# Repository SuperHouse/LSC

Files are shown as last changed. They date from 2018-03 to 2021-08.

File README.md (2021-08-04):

Home Automation Light Switch Controller
=======================================

Copyright 2019-2021 SuperHouse Automation Pty Ltd  www.superhouse.tv

A modular Light Switch Controller for DIY home automation projects.

This system uses UTP cable (typically Cat-5e because it's cheap) to
connect light switches to a central controller. The light switches
can be either very simple buttons or switches mounted in wall plates,
or smart switches with a microcontroller embedded.

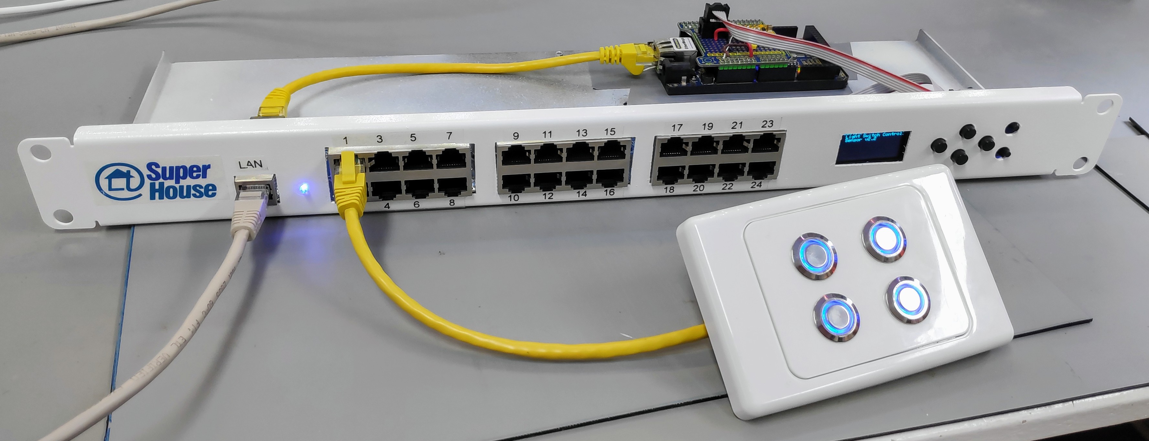
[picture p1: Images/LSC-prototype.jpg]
Light Switch Controller prototype


The LSC provides 12V power down the line to each wall plate, which can
be used for LED illumination or to power more advanced light switches.

Light switches pull one of 4 signal wires in the cable to 0V to indicate
that they have been activated. The LSC pulls the signal wires high
internally and detects when they are pulled low.

RJ45 sockets on the LSC are connected to I/O channels via I2C
addressable I/O buffers. Each RJ45 socket provides connections for
GND, 12V, and 4 signal lines.

An LSC can be built with different numbers of ports and interface
options.

The design files for the I2C to RJ45 breakouts are now in a separate
repository:

  https://github.com/SuperHouse/I2CRJ45

Features:

 * RJ45 sockets for connection to light switches over Cat-5
 * I2C interface with interrupt output

More information:

  http://www.superhouse.tv/lsc

INSTALLATION
------------
The design is saved as an EAGLE project. EAGLE PCB design software is
available from www.cadsoftusa.com free for non-commercial use. To use
this project download it and place the directory containing these files
into the "eagle" directory on your computer. Then open EAGLE and
navigate to the project.

FIRMWARE
--------
See [Universal State Monitor](https://github.com/SuperHouse/USM) for 
firmware which is compatible with the LSC.

CREDITS
-------
 * Jonathan Oxer jon@oxer.com.au

DISTRIBUTION
------------
The specific terms of distribution of this project are governed by the
license referenced below.

LICENSE
-------
Licensed under the TAPR Open Hardware License (www.tapr.org/OHL).
The "license" folder within this repository also contains a copy of
this license in plain text format.

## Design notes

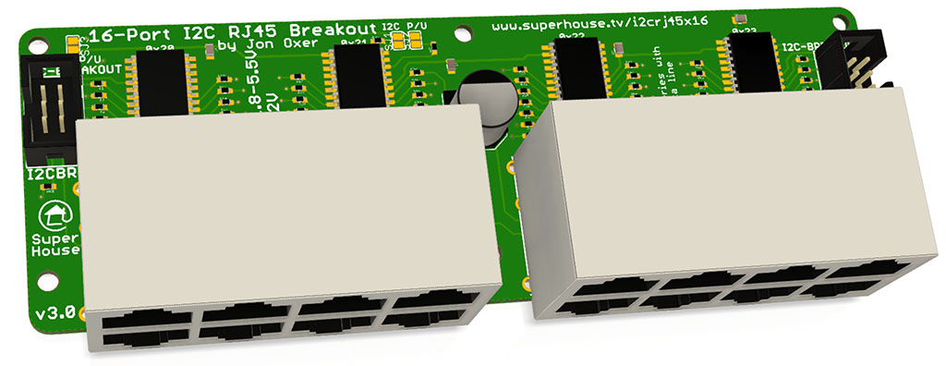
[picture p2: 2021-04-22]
Images/I2CRJ45X16-v3_0-render.jpg

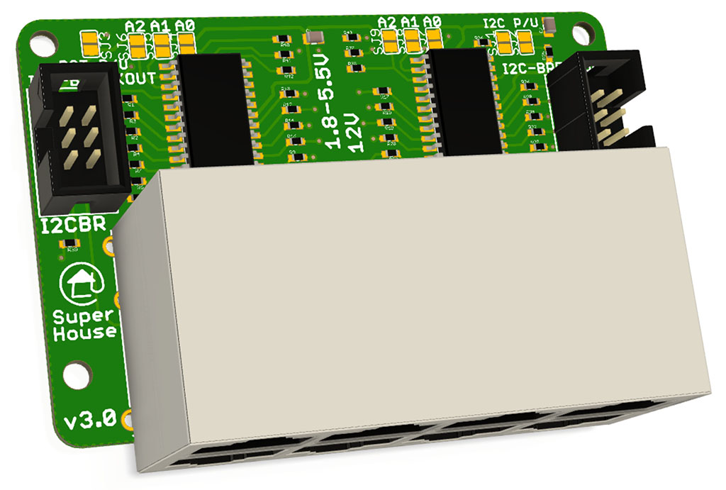
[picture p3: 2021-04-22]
Images/I2CRJ45X8-v3_0-render.jpg

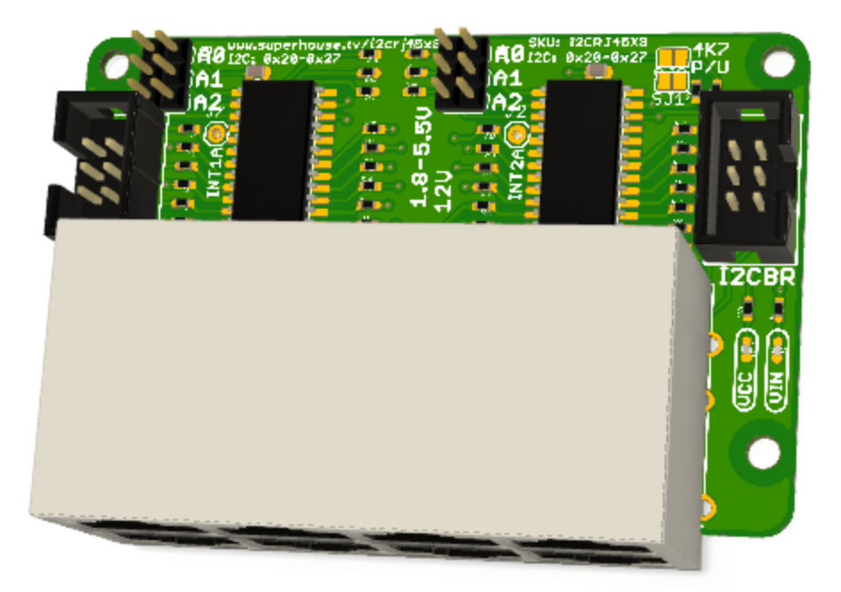
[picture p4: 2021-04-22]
Images/I2CRJ45X8-v2_2-render.jpg

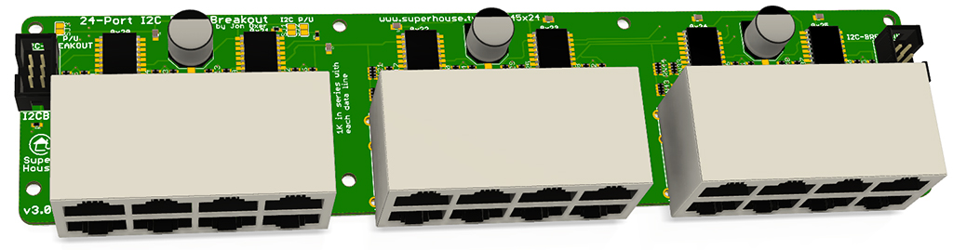
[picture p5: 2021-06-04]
Images/I2CRJ45X24-v3_0-render.jpg

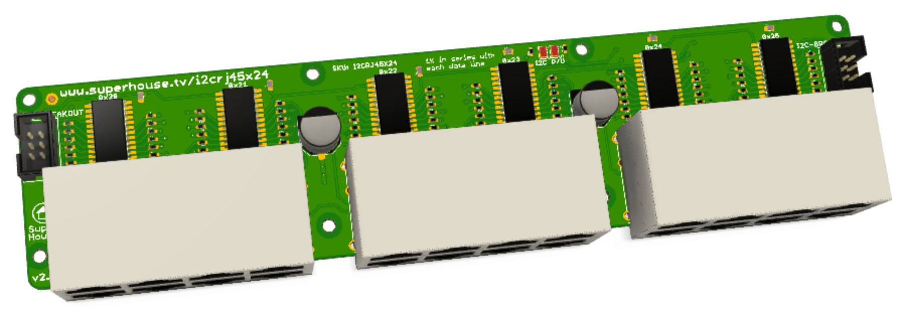
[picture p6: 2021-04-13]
Images/I2CRJ45X24-v2_2-render.jpg

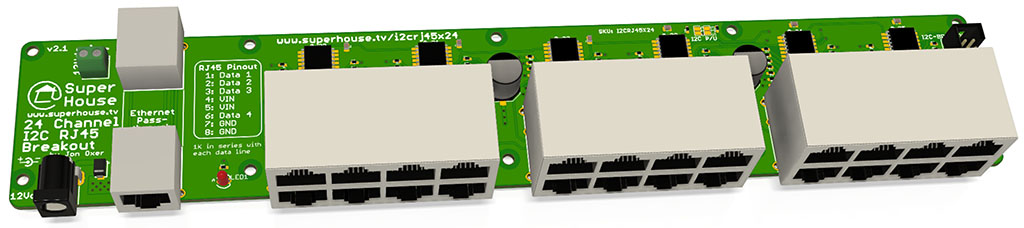
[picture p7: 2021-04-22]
Images/I2CRJ45X24PT-v2_1-render.jpg

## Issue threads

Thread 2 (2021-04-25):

Auto discover MCP23017

jonoxer, 2021-04-25:
Suggestion by Austin: scan I2C at startup and auto configure for number of input ports.

austinscreations, 2021-04-25:
could also be a way of detecting a failure, / outputting a warning to mqtt
glad you like the suggestion.

Sausages69, 2021-04-25:
Great idea :)

jonoxer, 2021-04-25:
This has been implemented by @sumnerboy12 using a scan starting at the base address, and ending at the first gap. This meets our short-term needs, but ultimately this needs to scan the entire range and skip any addresses that don't reply. The reason is that the control buttons on the OLED front panel are also on an MCP23017 but separate to the rest of the inputs, and it's always at the highest address. It will never be discovered if the scan stops at the first gap.

I'm leaving this issue open for now as a reminder for the future.

sumnerboy12, 2021-04-26:
See https://github.com/SuperHouse/LSC/pull/10 for further work on this.

sumnerboy12, 2021-04-26:
The code should now detect the OLED input button events and report them to MQTT. @jonoxer can you please test this on your Mega?

sumnerboy12, 2021-05-06:
This should be complete once #16 is merged.

sumnerboy12, 2021-05-09:
@jonoxer I think this can be closed now - the latest version supports I2C scanning properly.

Closed 2021-07-29.

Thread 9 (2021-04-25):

Add support for switches on inputs

jonoxer, 2021-04-25:
The current firmware assumes momentary buttons on inputs. It should be possible to configure any arbitrary input as being a switch instead of a button, so that it acts on every transition instead of just when the contact closes. Wall plates could then be assembled using regular mains switches so that they appear unmodified, and behave as expected.

sumnerboy12, 2021-05-20:
This has been implemented in https://github.com/sumnerboy12/LSC/pull/4 (of my fork). I have renamed the sketch since this now supports more than just light switch events, it will handle any binary input - i.e. BUTTON, SWITCH or CONTACT inputs, reporting appropriate events to MQTT.

I would be happy to create a PR to your repo if you think this has value?

NOTE: I have removed the OLED code for now, as I was trying to conserve space, plus I am unable to test since my OLED module appears to be busted.

Thanks to @moinmoin-sh for his help with developing this new firmeware!

sumnerboy12, 2021-05-22:
Just added support for TOGGLE switches, which report a `TOGGLE` event on any switch transition.

Closed 2021-07-29.

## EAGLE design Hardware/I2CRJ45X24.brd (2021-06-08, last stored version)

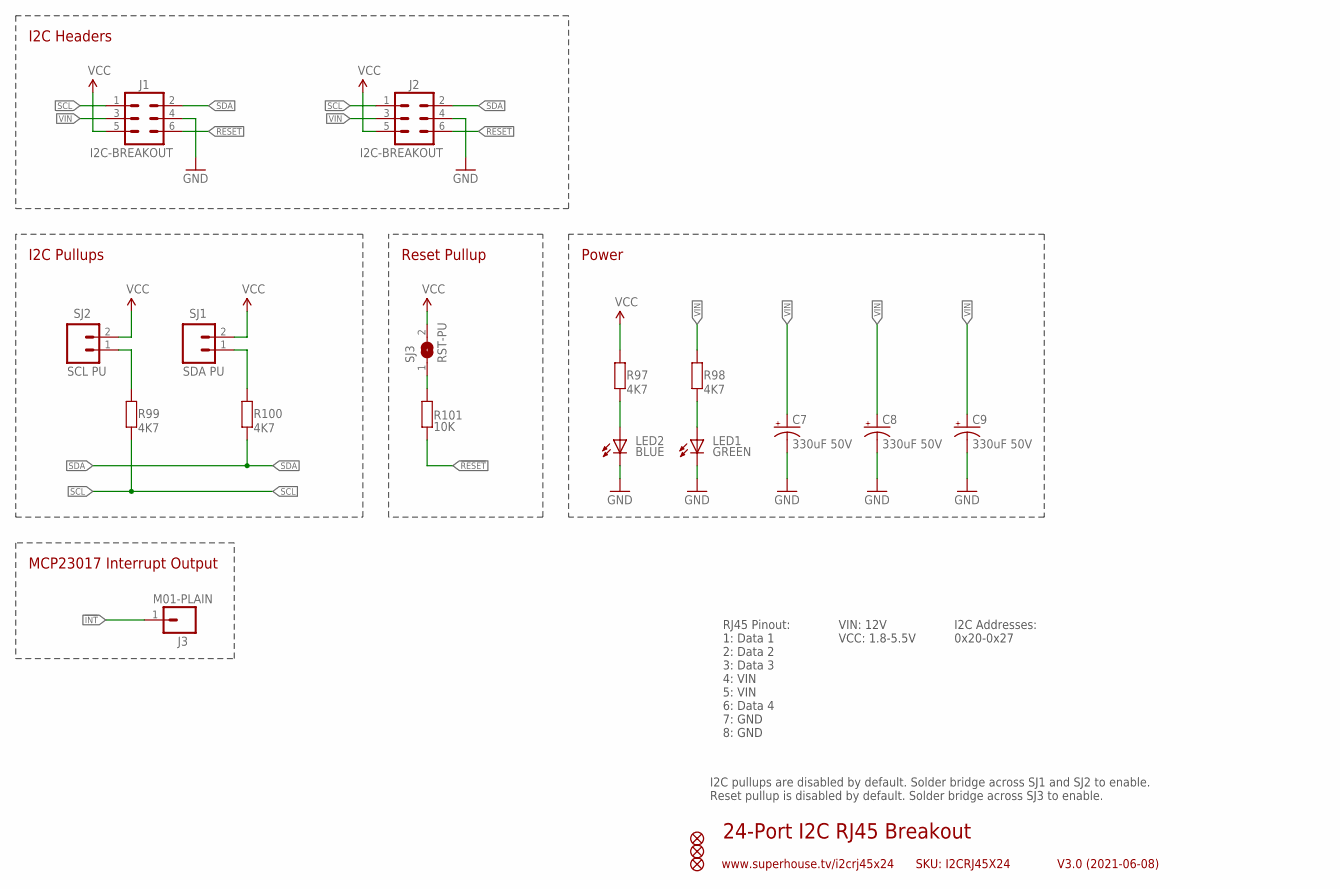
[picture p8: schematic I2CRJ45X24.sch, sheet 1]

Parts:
C7, C8, C9: 330uF 50V; PANASONIC_G
FID1, FID2, FID3: FIDUCIAL1X2.5; FIDUCIAL-1X2.5
J1, J2: I2C-BREAKOUT; 2X3-2.54-SHROUDED
J3: M01-PLAIN; 1X01
LED1: GREEN; LED-0603
LED2: BLUE; LED-0603
R97, R98, R99, R100: 4K7; R0603
R101: 10K; R0603
SJ1: SDA PU; 1X02-P
SJ2: SCL PU; 1X02-P
SJ3: RST-PU; SJ

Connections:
!INT: J3.1; also elsewhere on the board
!RESET: J1.6, J2.6, R101.1; also elsewhere on the board
GND: C7.-, C8.-, C9.-, J1.4, J2.4, LED1.C, LED2.C; also elsewhere on the board
unnamed: R99.2, SJ2.1
unnamed: R100.2, SJ1.1
unnamed: R101.2, SJ3.1
unnamed: LED2.A, R97.1
unnamed: LED1.A, R98.1
SCL: J1.1, J2.1, R99.1; also elsewhere on the board
SDA: J1.2, J2.2, R100.1; also elsewhere on the board
VCC: J1.5, J2.5, R97.2, SJ1.2, SJ2.2, SJ3.2; also elsewhere on the board
VIN: C7.+, C8.+, C9.+, J1.3, J2.3, R98.2; also elsewhere on the board

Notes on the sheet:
24-Port I2C RJ45 Breakout
V3.0 (2021-06-08)
www.superhouse.tv/i2crj45x24
SKU: I2CRJ45X24
RJ45 Pinout: 1: Data 1 2: Data 2 3: Data 3 4: VIN 5: VIN 6: Data 4 7: GND 8: GND
VIN: 12V VCC: 1.8-5.5V
I2C Addresses: 0x20-0x27
I2C Headers
MCP23017 Interrupt Output
I2C Pullups
I2C pullups are disabled by default. Solder bridge across SJ1 and SJ2 to enable. Reset pullup is disabled by default. Solder bridge across SJ3 to enable.
Power
Reset Pullup

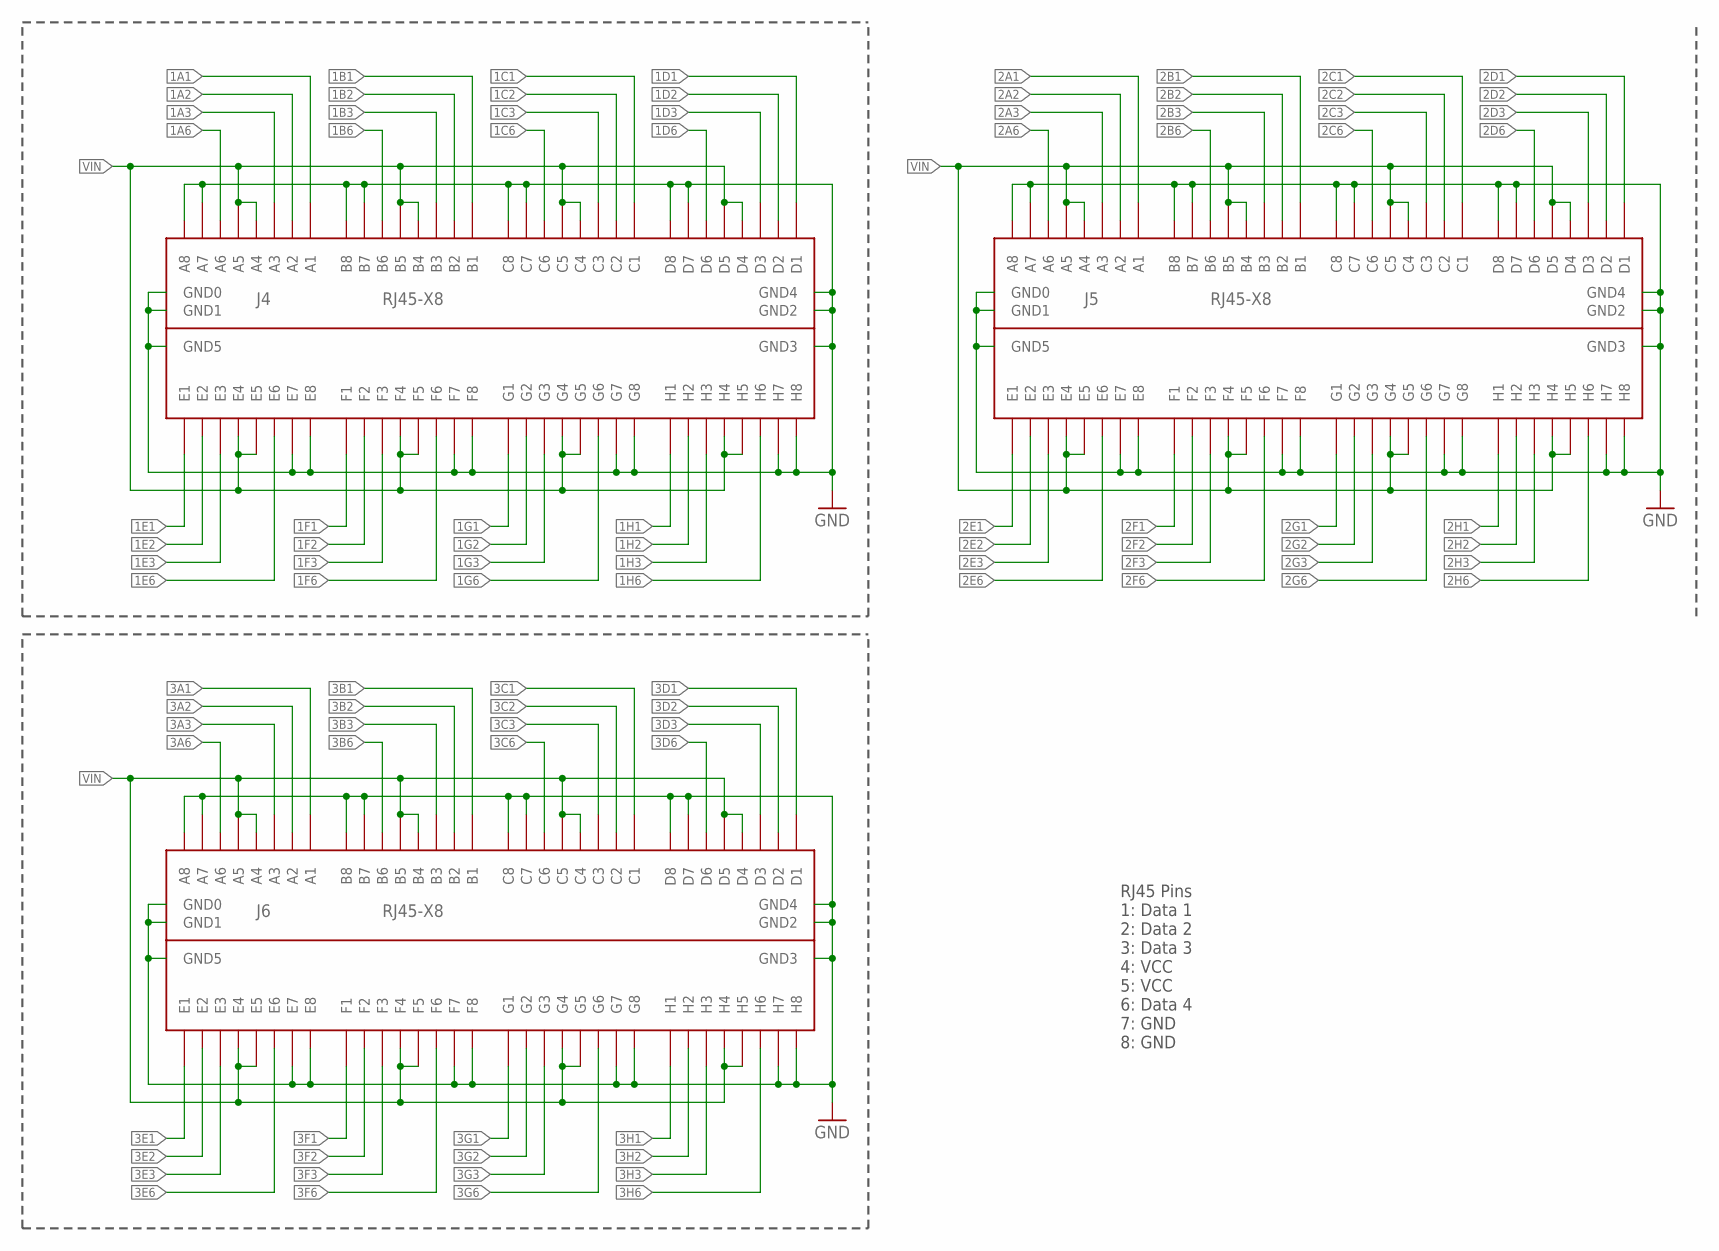
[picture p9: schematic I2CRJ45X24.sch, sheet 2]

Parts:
J4, J5, J6: RJ45-X8; RJ45-2X4

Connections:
1A1: J4.A1; also elsewhere on the board
1A2: J4.A2; also elsewhere on the board
1A3: J4.A3; also elsewhere on the board
1A6: J4.A6; also elsewhere on the board
1B1: J4.B1; also elsewhere on the board
1B2: J4.B2; also elsewhere on the board
1B3: J4.B3; also elsewhere on the board
1B6: J4.B6; also elsewhere on the board
1C1: J4.C1; also elsewhere on the board
1C2: J4.C2; also elsewhere on the board
1C3: J4.C3; also elsewhere on the board
1C6: J4.C6; also elsewhere on the board
1D1: J4.D1; also elsewhere on the board
1D2: J4.D2; also elsewhere on the board
1D3: J4.D3; also elsewhere on the board
1D6: J4.D6; also elsewhere on the board
1E1: J4.E1; also elsewhere on the board
1E2: J4.E2; also elsewhere on the board
1E3: J4.E3; also elsewhere on the board
1E6: J4.E6; also elsewhere on the board
1F1: J4.F1; also elsewhere on the board
1F2: J4.F2; also elsewhere on the board
1F3: J4.F3; also elsewhere on the board
1F6: J4.F6; also elsewhere on the board
1G1: J4.G1; also elsewhere on the board
1G2: J4.G2; also elsewhere on the board
1G3: J4.G3; also elsewhere on the board
1G6: J4.G6; also elsewhere on the board
1H1: J4.H1; also elsewhere on the board
1H2: J4.H2; also elsewhere on the board
1H3: J4.H3; also elsewhere on the board
1H6: J4.H6; also elsewhere on the board
2A1: J5.A1; also elsewhere on the board
2A2: J5.A2; also elsewhere on the board
2A3: J5.A3; also elsewhere on the board
2A6: J5.A6; also elsewhere on the board
2B1: J5.B1; also elsewhere on the board
2B2: J5.B2; also elsewhere on the board
2B3: J5.B3; also elsewhere on the board
2B6: J5.B6; also elsewhere on the board
2C1: J5.C1; also elsewhere on the board
2C2: J5.C2; also elsewhere on the board
2C3: J5.C3; also elsewhere on the board
2C6: J5.C6; also elsewhere on the board
2D1: J5.D1; also elsewhere on the board
2D2: J5.D2; also elsewhere on the board
2D3: J5.D3; also elsewhere on the board
2D6: J5.D6; also elsewhere on the board
2E1: J5.E1; also elsewhere on the board
2E2: J5.E2; also elsewhere on the board
2E3: J5.E3; also elsewhere on the board
2E6: J5.E6; also elsewhere on the board
2F1: J5.F1; also elsewhere on the board
2F2: J5.F2; also elsewhere on the board
2F3: J5.F3; also elsewhere on the board
2F6: J5.F6; also elsewhere on the board
2G1: J5.G1; also elsewhere on the board
2G2: J5.G2; also elsewhere on the board
2G3: J5.G3; also elsewhere on the board
2G6: J5.G6; also elsewhere on the board
2H1: J5.H1; also elsewhere on the board
2H2: J5.H2; also elsewhere on the board
2H3: J5.H3; also elsewhere on the board
2H6: J5.H6; also elsewhere on the board
3A1: J6.A1; also elsewhere on the board
3A2: J6.A2; also elsewhere on the board
3A3: J6.A3; also elsewhere on the board
3A6: J6.A6; also elsewhere on the board
3B1: J6.B1; also elsewhere on the board
3B2: J6.B2; also elsewhere on the board
3B3: J6.B3; also elsewhere on the board
3B6: J6.B6; also elsewhere on the board
3C1: J6.C1; also elsewhere on the board
3C2: J6.C2; also elsewhere on the board
3C3: J6.C3; also elsewhere on the board
3C6: J6.C6; also elsewhere on the board
3D1: J6.D1; also elsewhere on the board
3D2: J6.D2; also elsewhere on the board
3D3: J6.D3; also elsewhere on the board
3D6: J6.D6; also elsewhere on the board
3E1: J6.E1; also elsewhere on the board
3E2: J6.E2; also elsewhere on the board
3E3: J6.E3; also elsewhere on the board
3E6: J6.E6; also elsewhere on the board
3F1: J6.F1; also elsewhere on the board
3F2: J6.F2; also elsewhere on the board
3F3: J6.F3; also elsewhere on the board
3F6: J6.F6; also elsewhere on the board
3G1: J6.G1; also elsewhere on the board
3G2: J6.G2; also elsewhere on the board
3G3: J6.G3; also elsewhere on the board
3G6: J6.G6; also elsewhere on the board
3H1: J6.H1; also elsewhere on the board
3H2: J6.H2; also elsewhere on the board
3H3: J6.H3; also elsewhere on the board
3H6: J6.H6; also elsewhere on the board
GND: J4.A7, J4.A8, J4.B7, J4.B8, J4.C7, J4.C8, J4.D7, J4.D8, J4.E7, J4.E8, J4.F7, J4.F8, J4.G7, J4.G8, J4.GND0, J4.GND1, J4.GND2, J4.GND3, J4.GND4, J4.GND5, J4.H7, J4.H8, J5.A7, J5.A8, J5.B7, J5.B8, J5.C7, J5.C8, J5.D7, J5.D8, J5.E7, J5.E8, J5.F7, J5.F8, J5.G7, J5.G8, J5.GND0, J5.GND1, J5.GND2, J5.GND3, J5.GND4, J5.GND5, J5.H7, J5.H8, J6.A7, J6.A8, J6.B7, J6.B8, J6.C7, J6.C8, J6.D7, J6.D8, J6.E7, J6.E8, J6.F7, J6.F8, J6.G7, J6.G8, J6.GND0, J6.GND1, J6.GND2, J6.GND3, J6.GND4, J6.GND5, J6.H7, J6.H8; also elsewhere on the board
VIN: J4.A4, J4.A5, J4.B4, J4.B5, J4.C4, J4.C5, J4.D4, J4.D5, J4.E4, J4.E5, J4.F4, J4.F5, J4.G4, J4.G5, J4.H4, J4.H5, J5.A4, J5.A5, J5.B4, J5.B5, J5.C4, J5.C5, J5.D4, J5.D5, J5.E4, J5.E5, J5.F4, J5.F5, J5.G4, J5.G5, J5.H4, J5.H5, J6.A4, J6.A5, J6.B4, J6.B5, J6.C4, J6.C5, J6.D4, J6.D5, J6.E4, J6.E5, J6.F4, J6.F5, J6.G4, J6.G5, J6.H4, J6.H5; also elsewhere on the board

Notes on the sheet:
RJ45 Pins 1: Data 1 2: Data 2 3: Data 3 4: VCC 5: VCC 6: Data 4 7: GND 8: GND

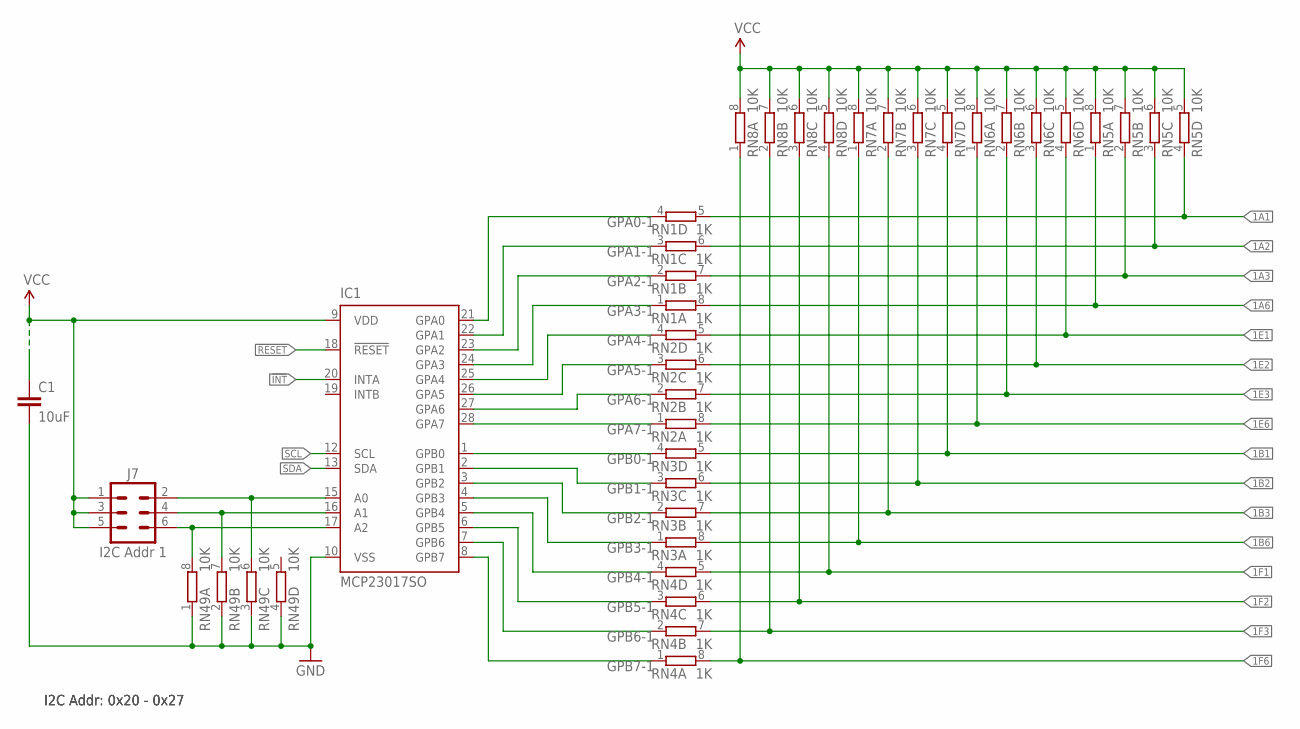
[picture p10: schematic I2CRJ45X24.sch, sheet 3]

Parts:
C1: 10uF; C0805
IC1: MCP23017SO; SO28W
J7: I2C Addr 1; 2X03-P
RN1, RN2, RN3, RN4: 1K; CAY16
RN5, RN6, RN7, RN8, RN49: 10K; CAY16

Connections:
1A1: RN1.5 (2), RN5.4 (1); also elsewhere on the board
1A2: RN1.6 (2), RN5.3 (1); also elsewhere on the board
1A3: RN1.7 (2), RN5.2 (1); also elsewhere on the board
1A6: RN1.8 (2), RN5.1; also elsewhere on the board
1B1: RN3.5 (2), RN7.4 (1); also elsewhere on the board
1B2: RN3.6 (2), RN7.3 (1); also elsewhere on the board
1B3: RN3.7 (2), RN7.2 (1); also elsewhere on the board
1B6: RN3.8 (2), RN7.1; also elsewhere on the board
1E1: RN2.5 (2), RN6.4 (1); also elsewhere on the board
1E2: RN2.6 (2), RN6.3 (1); also elsewhere on the board
1E3: RN2.7 (2), RN6.2 (1); also elsewhere on the board
1E6: RN2.8 (2), RN6.1; also elsewhere on the board
1F1: RN4.5 (2), RN8.4 (1); also elsewhere on the board
1F2: RN4.6 (2), RN8.3 (1); also elsewhere on the board
1F3: RN4.7 (2), RN8.2 (1); also elsewhere on the board
1F6: RN4.8 (2), RN8.1; also elsewhere on the board
!INT: IC1.20 (INTA); also elsewhere on the board
!RESET: IC1.18 (!RESET); also elsewhere on the board
GND: C1.2, IC1.10 (VSS), RN49.1, RN49.2 (1), RN49.3 (1), RN49.4 (1); also elsewhere on the board
GPA0-1: IC1.21 (GPA0), RN1.4 (1)
GPA1-1: IC1.22 (GPA1), RN1.3 (1)
GPA2-1: IC1.23 (GPA2), RN1.2 (1)
GPA3-1: IC1.24 (GPA3), RN1.1
GPA4-1: IC1.25 (GPA4), RN2.4 (1)
GPA5-1: IC1.26 (GPA5), RN2.3 (1)
GPA6-1: IC1.27 (GPA6), RN2.2 (1)
GPA7-1: IC1.28 (GPA7), RN2.1
GPB0-1: IC1.1 (GPB0), RN3.4 (1)
GPB1-1: IC1.2 (GPB1), RN3.3 (1)
GPB2-1: IC1.3 (GPB2), RN3.2 (1)
GPB3-1: IC1.4 (GPB3), RN3.1
GPB4-1: IC1.5 (GPB4), RN4.4 (1)
GPB5-1: IC1.6 (GPB5), RN4.3 (1)
GPB6-1: IC1.7 (GPB6), RN4.2 (1)
GPB7-1: IC1.8 (GPB7), RN4.1
unnamed: IC1.17 (A2), J7.6, RN49.8 (2)
unnamed: IC1.16 (A1), J7.4, RN49.7 (2)
unnamed: IC1.15 (A0), J7.2, RN49.6 (2)
SCL: IC1.12 (SCL); also elsewhere on the board
SDA: IC1.13 (SDA); also elsewhere on the board
VCC: C1.1, IC1.9 (VDD), J7.1, J7.3, J7.5, RN5.5 (2), RN5.6 (2), RN5.7 (2), RN5.8 (2), RN6.5 (2), RN6.6 (2), RN6.7 (2), RN6.8 (2), RN7.5 (2), RN7.6 (2), RN7.7 (2), RN7.8 (2), RN8.5 (2), RN8.6 (2), RN8.7 (2), RN8.8 (2); also elsewhere on the board

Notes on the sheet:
I2C Addr: 0x20 - 0x27

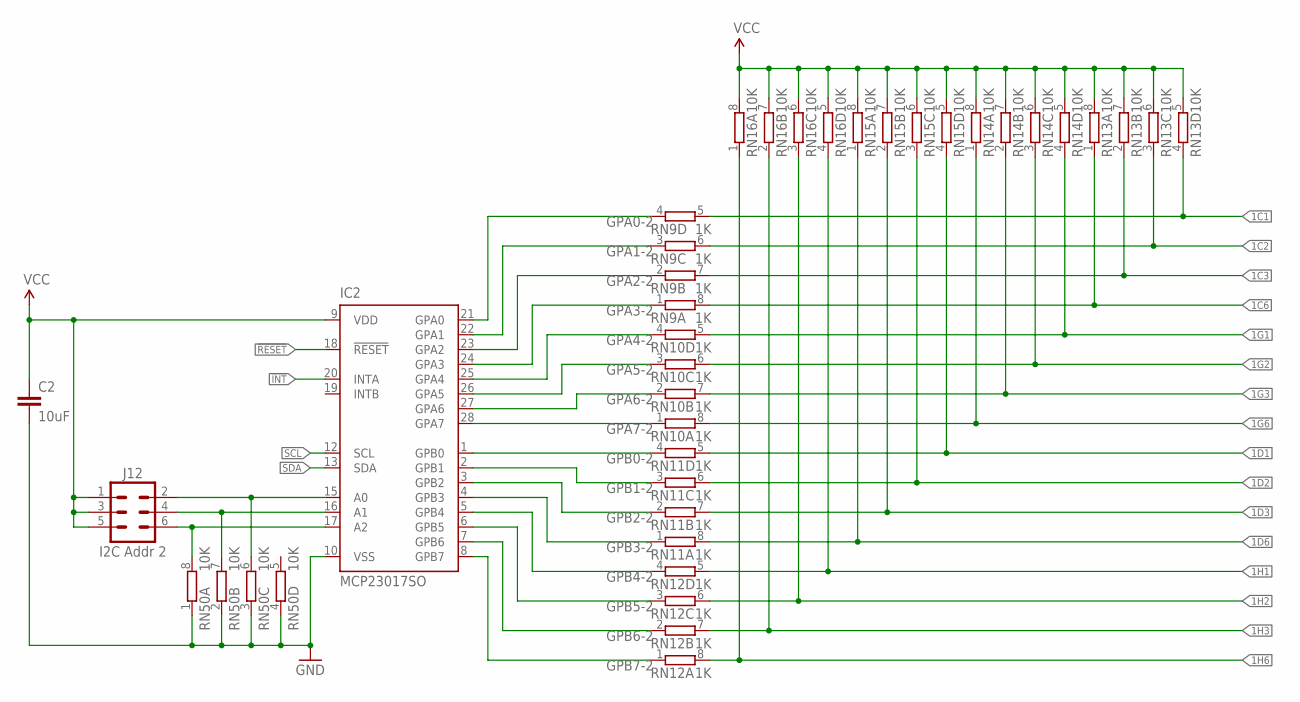
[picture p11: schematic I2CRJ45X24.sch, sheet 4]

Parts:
C2: 10uF; C0805
IC2: MCP23017SO; SO28W
J12: I2C Addr 2; 2X03-P
RN9, RN10, RN11, RN12: 1K; CAY16
RN13, RN14, RN15, RN16, RN50: 10K; CAY16

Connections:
1C1: RN9.5 (2), RN13.4 (1); also elsewhere on the board
1C2: RN9.6 (2), RN13.3 (1); also elsewhere on the board
1C3: RN9.7 (2), RN13.2 (1); also elsewhere on the board
1C6: RN9.8 (2), RN13.1; also elsewhere on the board
1D1: RN11.5 (2), RN15.4 (1); also elsewhere on the board
1D2: RN11.6 (2), RN15.3 (1); also elsewhere on the board
1D3: RN11.7 (2), RN15.2 (1); also elsewhere on the board
1D6: RN11.8 (2), RN15.1; also elsewhere on the board
1G1: RN10.5 (2), RN14.4 (1); also elsewhere on the board
1G2: RN10.6 (2), RN14.3 (1); also elsewhere on the board
1G3: RN10.7 (2), RN14.2 (1); also elsewhere on the board
1G6: RN10.8 (2), RN14.1; also elsewhere on the board
1H1: RN12.5 (2), RN16.4 (1); also elsewhere on the board
1H2: RN12.6 (2), RN16.3 (1); also elsewhere on the board
1H3: RN12.7 (2), RN16.2 (1); also elsewhere on the board
1H6: RN12.8 (2), RN16.1; also elsewhere on the board
!INT: IC2.20 (INTA); also elsewhere on the board
!RESET: IC2.18 (!RESET); also elsewhere on the board
GND: C2.2, IC2.10 (VSS), RN50.1, RN50.2 (1), RN50.3 (1), RN50.4 (1); also elsewhere on the board
GPA0-2: IC2.21 (GPA0), RN9.4 (1)
GPA1-2: IC2.22 (GPA1), RN9.3 (1)
GPA2-2: IC2.23 (GPA2), RN9.2 (1)
GPA3-2: IC2.24 (GPA3), RN9.1
GPA4-2: IC2.25 (GPA4), RN10.4 (1)
GPA5-2: IC2.26 (GPA5), RN10.3 (1)
GPA6-2: IC2.27 (GPA6), RN10.2 (1)
GPA7-2: IC2.28 (GPA7), RN10.1
GPB0-2: IC2.1 (GPB0), RN11.4 (1)
GPB1-2: IC2.2 (GPB1), RN11.3 (1)
GPB2-2: IC2.3 (GPB2), RN11.2 (1)
GPB3-2: IC2.4 (GPB3), RN11.1
GPB4-2: IC2.5 (GPB4), RN12.4 (1)
GPB5-2: IC2.6 (GPB5), RN12.3 (1)
GPB6-2: IC2.7 (GPB6), RN12.2 (1)
GPB7-2: IC2.8 (GPB7), RN12.1
unnamed: IC2.15 (A0), J12.2, RN50.6 (2)
unnamed: IC2.16 (A1), J12.4, RN50.7 (2)
unnamed: IC2.17 (A2), J12.6, RN50.8 (2)
SCL: IC2.12 (SCL); also elsewhere on the board
SDA: IC2.13 (SDA); also elsewhere on the board
VCC: C2.1, IC2.9 (VDD), J12.1, J12.3, J12.5, RN13.5 (2), RN13.6 (2), RN13.7 (2), RN13.8 (2), RN14.5 (2), RN14.6 (2), RN14.7 (2), RN14.8 (2), RN15.5 (2), RN15.6 (2), RN15.7 (2), RN15.8 (2), RN16.5 (2), RN16.6 (2), RN16.7 (2), RN16.8 (2); also elsewhere on the board

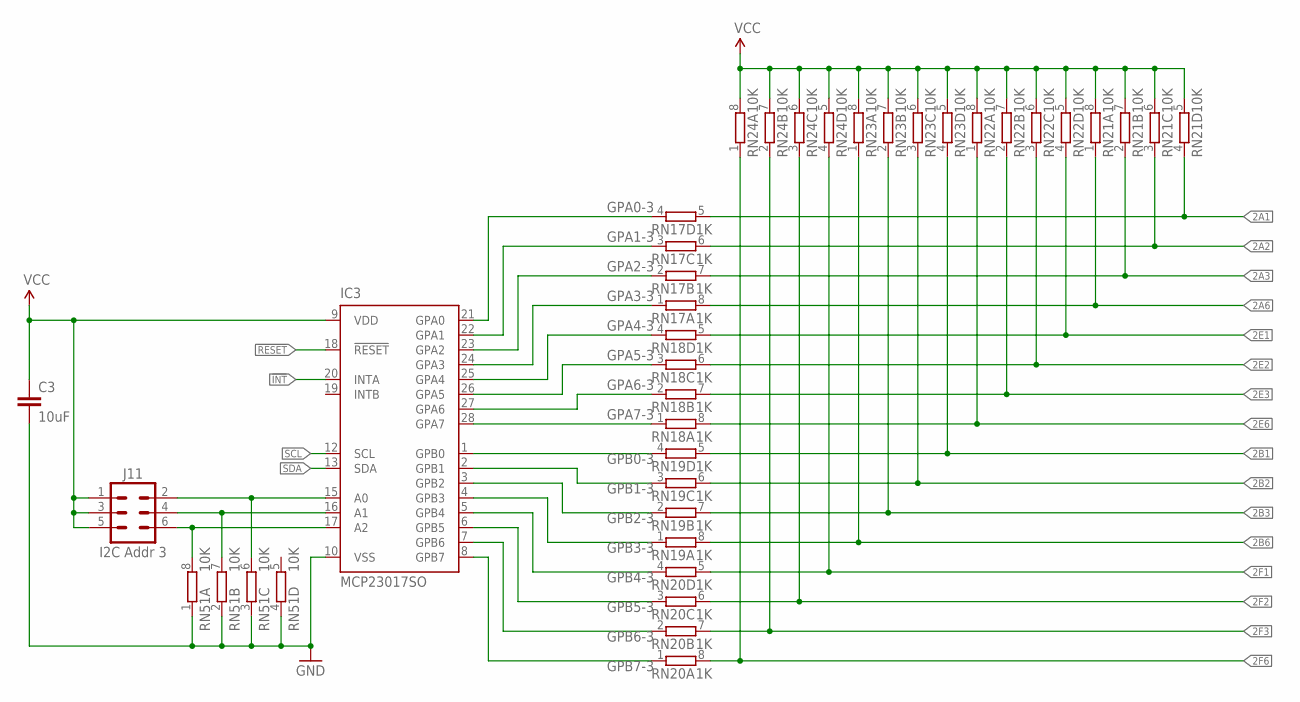
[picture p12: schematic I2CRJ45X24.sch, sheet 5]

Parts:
C3: 10uF; C0805
IC3: MCP23017SO; SO28W
J11: I2C Addr 3; 2X03-P
RN17, RN18, RN19, RN20: 1K; CAY16
RN21, RN22, RN23, RN24, RN51: 10K; CAY16

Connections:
2A1: RN17.5 (2), RN21.4 (1); also elsewhere on the board
2A2: RN17.6 (2), RN21.3 (1); also elsewhere on the board
2A3: RN17.7 (2), RN21.2 (1); also elsewhere on the board
2A6: RN17.8 (2), RN21.1; also elsewhere on the board
2B1: RN19.5 (2), RN23.4 (1); also elsewhere on the board
2B2: RN19.6 (2), RN23.3 (1); also elsewhere on the board
2B3: RN19.7 (2), RN23.2 (1); also elsewhere on the board
2B6: RN19.8 (2), RN23.1; also elsewhere on the board
2E1: RN18.5 (2), RN22.4 (1); also elsewhere on the board
2E2: RN18.6 (2), RN22.3 (1); also elsewhere on the board
2E3: RN18.7 (2), RN22.2 (1); also elsewhere on the board
2E6: RN18.8 (2), RN22.1; also elsewhere on the board
2F1: RN20.5 (2), RN24.4 (1); also elsewhere on the board
2F2: RN20.6 (2), RN24.3 (1); also elsewhere on the board
2F3: RN20.7 (2), RN24.2 (1); also elsewhere on the board
2F6: RN20.8 (2), RN24.1; also elsewhere on the board
!INT: IC3.20 (INTA); also elsewhere on the board
!RESET: IC3.18 (!RESET); also elsewhere on the board
GND: C3.2, IC3.10 (VSS), RN51.1, RN51.2 (1), RN51.3 (1), RN51.4 (1); also elsewhere on the board
GPA0-3: IC3.21 (GPA0), RN17.4 (1)
GPA1-3: IC3.22 (GPA1), RN17.3 (1)
GPA2-3: IC3.23 (GPA2), RN17.2 (1)
GPA3-3: IC3.24 (GPA3), RN17.1
GPA4-3: IC3.25 (GPA4), RN18.4 (1)
GPA5-3: IC3.26 (GPA5), RN18.3 (1)
GPA6-3: IC3.27 (GPA6), RN18.2 (1)
GPA7-3: IC3.28 (GPA7), RN18.1
GPB0-3: IC3.1 (GPB0), RN19.4 (1)
GPB1-3: IC3.2 (GPB1), RN19.3 (1)
GPB2-3: IC3.3 (GPB2), RN19.2 (1)
GPB3-3: IC3.4 (GPB3), RN19.1
GPB4-3: IC3.5 (GPB4), RN20.4 (1)
GPB5-3: IC3.6 (GPB5), RN20.3 (1)
GPB6-3: IC3.7 (GPB6), RN20.2 (1)
GPB7-3: IC3.8 (GPB7), RN20.1
unnamed: IC3.17 (A2), J11.6, RN51.8 (2)
unnamed: IC3.15 (A0), J11.2, RN51.6 (2)
unnamed: IC3.16 (A1), J11.4, RN51.7 (2)
SCL: IC3.12 (SCL); also elsewhere on the board
SDA: IC3.13 (SDA); also elsewhere on the board
VCC: C3.1, IC3.9 (VDD), J11.1, J11.3, J11.5, RN21.5 (2), RN21.6 (2), RN21.7 (2), RN21.8 (2), RN22.5 (2), RN22.6 (2), RN22.7 (2), RN22.8 (2), RN23.5 (2), RN23.6 (2), RN23.7 (2), RN23.8 (2), RN24.5 (2), RN24.6 (2), RN24.7 (2), RN24.8 (2); also elsewhere on the board

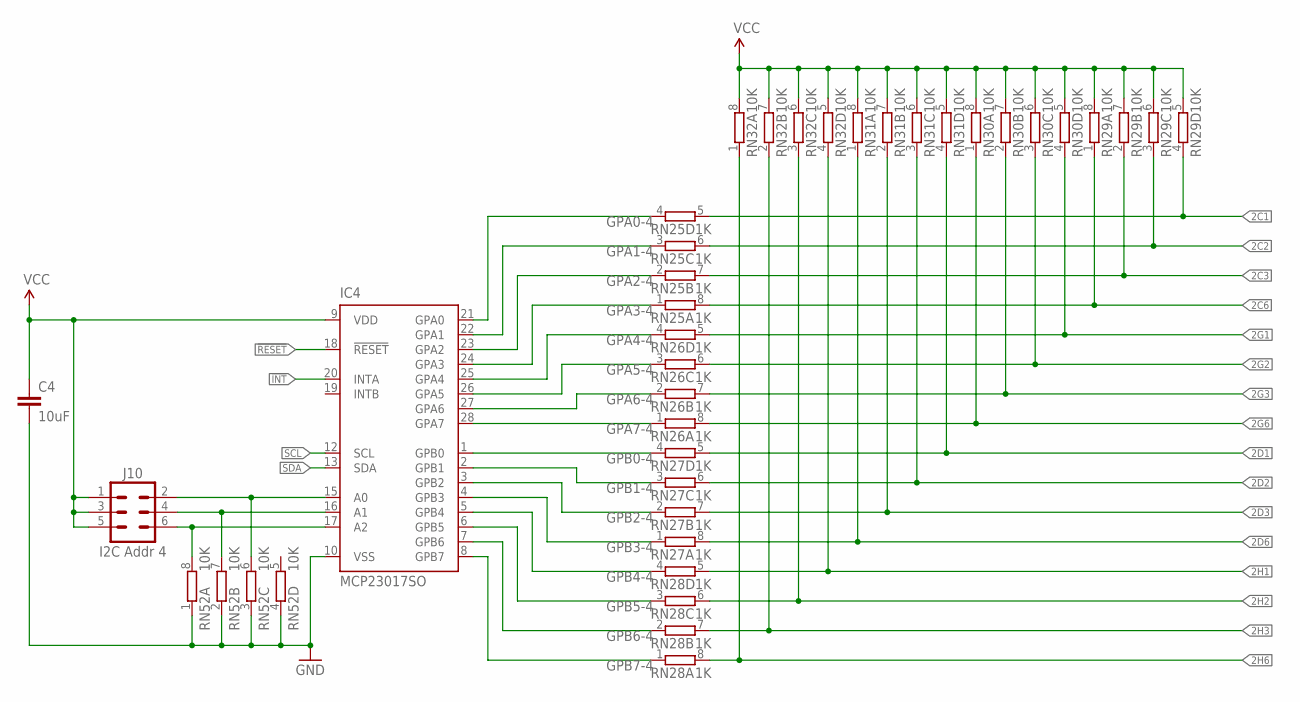
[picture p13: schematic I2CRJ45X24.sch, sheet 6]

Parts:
C4: 10uF; C0805
IC4: MCP23017SO; SO28W
J10: I2C Addr 4; 2X03-P
RN25, RN26, RN27, RN28: 1K; CAY16
RN29, RN30, RN31, RN32, RN52: 10K; CAY16

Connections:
2C1: RN25.5 (2), RN29.4 (1); also elsewhere on the board
2C2: RN25.6 (2), RN29.3 (1); also elsewhere on the board
2C3: RN25.7 (2), RN29.2 (1); also elsewhere on the board
2C6: RN25.8 (2), RN29.1; also elsewhere on the board
2D1: RN27.5 (2), RN31.4 (1); also elsewhere on the board
2D2: RN27.6 (2), RN31.3 (1); also elsewhere on the board
2D3: RN27.7 (2), RN31.2 (1); also elsewhere on the board
2D6: RN27.8 (2), RN31.1; also elsewhere on the board
2G1: RN26.5 (2), RN30.4 (1); also elsewhere on the board
2G2: RN26.6 (2), RN30.3 (1); also elsewhere on the board
2G3: RN26.7 (2), RN30.2 (1); also elsewhere on the board
2G6: RN26.8 (2), RN30.1; also elsewhere on the board
2H1: RN28.5 (2), RN32.4 (1); also elsewhere on the board
2H2: RN28.6 (2), RN32.3 (1); also elsewhere on the board
2H3: RN28.7 (2), RN32.2 (1); also elsewhere on the board
2H6: RN28.8 (2), RN32.1; also elsewhere on the board
!INT: IC4.20 (INTA); also elsewhere on the board
!RESET: IC4.18 (!RESET); also elsewhere on the board
GND: C4.2, IC4.10 (VSS), RN52.1, RN52.2 (1), RN52.3 (1), RN52.4 (1); also elsewhere on the board
GPA0-4: IC4.21 (GPA0), RN25.4 (1)
GPA1-4: IC4.22 (GPA1), RN25.3 (1)
GPA2-4: IC4.23 (GPA2), RN25.2 (1)
GPA3-4: IC4.24 (GPA3), RN25.1
GPA4-4: IC4.25 (GPA4), RN26.4 (1)
GPA5-4: IC4.26 (GPA5), RN26.3 (1)
GPA6-4: IC4.27 (GPA6), RN26.2 (1)
GPA7-4: IC4.28 (GPA7), RN26.1
GPB0-4: IC4.1 (GPB0), RN27.4 (1)
GPB1-4: IC4.2 (GPB1), RN27.3 (1)
GPB2-4: IC4.3 (GPB2), RN27.2 (1)
GPB3-4: IC4.4 (GPB3), RN27.1
GPB4-4: IC4.5 (GPB4), RN28.4 (1)
GPB5-4: IC4.6 (GPB5), RN28.3 (1)
GPB6-4: IC4.7 (GPB6), RN28.2 (1)
GPB7-4: IC4.8 (GPB7), RN28.1
unnamed: IC4.17 (A2), J10.6, RN52.8 (2)
unnamed: IC4.15 (A0), J10.2, RN52.6 (2)
unnamed: IC4.16 (A1), J10.4, RN52.7 (2)
SCL: IC4.12 (SCL); also elsewhere on the board
SDA: IC4.13 (SDA); also elsewhere on the board
VCC: C4.1, IC4.9 (VDD), J10.1, J10.3, J10.5, RN29.5 (2), RN29.6 (2), RN29.7 (2), RN29.8 (2), RN30.5 (2), RN30.6 (2), RN30.7 (2), RN30.8 (2), RN31.5 (2), RN31.6 (2), RN31.7 (2), RN31.8 (2), RN32.5 (2), RN32.6 (2), RN32.7 (2), RN32.8 (2); also elsewhere on the board

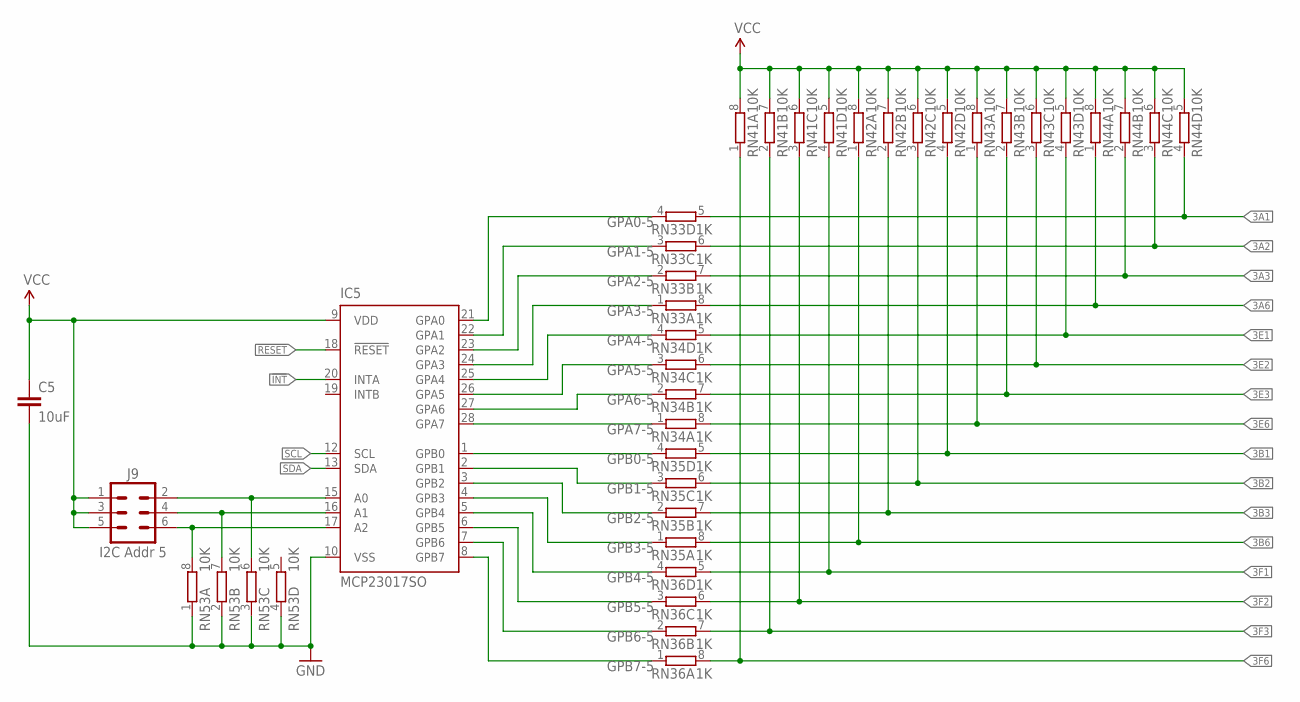
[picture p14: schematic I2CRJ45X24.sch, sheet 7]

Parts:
C5: 10uF; C0805
IC5: MCP23017SO; SO28W
J9: I2C Addr 5; 2X03-P
RN33, RN34, RN35, RN36: 1K; CAY16
RN41, RN42, RN43, RN44, RN53: 10K; CAY16

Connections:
3A1: RN33.5 (2), RN44.4 (1); also elsewhere on the board
3A2: RN33.6 (2), RN44.3 (1); also elsewhere on the board
3A3: RN33.7 (2), RN44.2 (1); also elsewhere on the board
3A6: RN33.8 (2), RN44.1; also elsewhere on the board
3B1: RN35.5 (2), RN42.4 (1); also elsewhere on the board
3B2: RN35.6 (2), RN42.3 (1); also elsewhere on the board
3B3: RN35.7 (2), RN42.2 (1); also elsewhere on the board
3B6: RN35.8 (2), RN42.1; also elsewhere on the board
3E1: RN34.5 (2), RN43.4 (1); also elsewhere on the board
3E2: RN34.6 (2), RN43.3 (1); also elsewhere on the board
3E3: RN34.7 (2), RN43.2 (1); also elsewhere on the board
3E6: RN34.8 (2), RN43.1; also elsewhere on the board
3F1: RN36.5 (2), RN41.4 (1); also elsewhere on the board
3F2: RN36.6 (2), RN41.3 (1); also elsewhere on the board
3F3: RN36.7 (2), RN41.2 (1); also elsewhere on the board
3F6: RN36.8 (2), RN41.1; also elsewhere on the board
!INT: IC5.20 (INTA); also elsewhere on the board
!RESET: IC5.18 (!RESET); also elsewhere on the board
GND: C5.2, IC5.10 (VSS), RN53.1, RN53.2 (1), RN53.3 (1), RN53.4 (1); also elsewhere on the board
GPA0-5: IC5.21 (GPA0), RN33.4 (1)
GPA1-5: IC5.22 (GPA1), RN33.3 (1)
GPA2-5: IC5.23 (GPA2), RN33.2 (1)
GPA3-5: IC5.24 (GPA3), RN33.1
GPA4-5: IC5.25 (GPA4), RN34.4 (1)
GPA5-5: IC5.26 (GPA5), RN34.3 (1)
GPA6-5: IC5.27 (GPA6), RN34.2 (1)
GPA7-5: IC5.28 (GPA7), RN34.1
GPB0-5: IC5.1 (GPB0), RN35.4 (1)
GPB1-5: IC5.2 (GPB1), RN35.3 (1)
GPB2-5: IC5.3 (GPB2), RN35.2 (1)
GPB3-5: IC5.4 (GPB3), RN35.1
GPB4-5: IC5.5 (GPB4), RN36.4 (1)
GPB5-5: IC5.6 (GPB5), RN36.3 (1)
GPB6-5: IC5.7 (GPB6), RN36.2 (1)
GPB7-5: IC5.8 (GPB7), RN36.1
unnamed: IC5.17 (A2), J9.6, RN53.8 (2)
unnamed: IC5.15 (A0), J9.2, RN53.6 (2)
unnamed: IC5.16 (A1), J9.4, RN53.7 (2)
SCL: IC5.12 (SCL); also elsewhere on the board
SDA: IC5.13 (SDA); also elsewhere on the board
VCC: C5.1, IC5.9 (VDD), J9.1, J9.3, J9.5, RN41.5 (2), RN41.6 (2), RN41.7 (2), RN41.8 (2), RN42.5 (2), RN42.6 (2), RN42.7 (2), RN42.8 (2), RN43.5 (2), RN43.6 (2), RN43.7 (2), RN43.8 (2), RN44.5 (2), RN44.6 (2), RN44.7 (2), RN44.8 (2); also elsewhere on the board

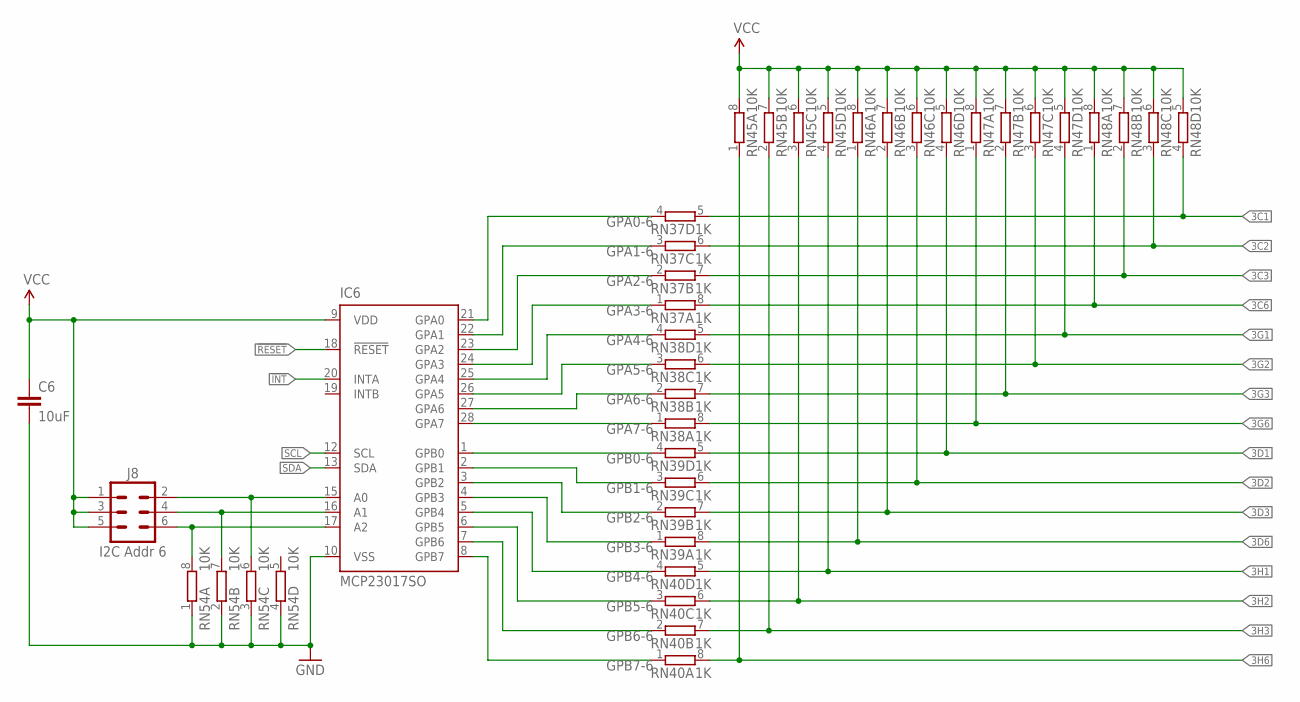
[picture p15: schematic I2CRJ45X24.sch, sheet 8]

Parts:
C6: 10uF; C0805
IC6: MCP23017SO; SO28W
J8: I2C Addr 6; 2X03-P
RN37, RN38, RN39, RN40: 1K; CAY16
RN45, RN46, RN47, RN48, RN54: 10K; CAY16

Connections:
3C1: RN37.5 (2), RN48.4 (1); also elsewhere on the board
3C2: RN37.6 (2), RN48.3 (1); also elsewhere on the board
3C3: RN37.7 (2), RN48.2 (1); also elsewhere on the board
3C6: RN37.8 (2), RN48.1; also elsewhere on the board
3D1: RN39.5 (2), RN46.4 (1); also elsewhere on the board
3D2: RN39.6 (2), RN46.3 (1); also elsewhere on the board
3D3: RN39.7 (2), RN46.2 (1); also elsewhere on the board
3D6: RN39.8 (2), RN46.1; also elsewhere on the board
3G1: RN38.5 (2), RN47.4 (1); also elsewhere on the board
3G2: RN38.6 (2), RN47.3 (1); also elsewhere on the board
3G3: RN38.7 (2), RN47.2 (1); also elsewhere on the board
3G6: RN38.8 (2), RN47.1; also elsewhere on the board
3H1: RN40.5 (2), RN45.4 (1); also elsewhere on the board
3H2: RN40.6 (2), RN45.3 (1); also elsewhere on the board
3H3: RN40.7 (2), RN45.2 (1); also elsewhere on the board
3H6: RN40.8 (2), RN45.1; also elsewhere on the board
!INT: IC6.20 (INTA); also elsewhere on the board
!RESET: IC6.18 (!RESET); also elsewhere on the board
GND: C6.2, IC6.10 (VSS), RN54.1, RN54.2 (1), RN54.3 (1), RN54.4 (1); also elsewhere on the board
GPA0-6: IC6.21 (GPA0), RN37.4 (1)
GPA1-6: IC6.22 (GPA1), RN37.3 (1)
GPA2-6: IC6.23 (GPA2), RN37.2 (1)
GPA3-6: IC6.24 (GPA3), RN37.1
GPA4-6: IC6.25 (GPA4), RN38.4 (1)
GPA5-6: IC6.26 (GPA5), RN38.3 (1)
GPA6-6: IC6.27 (GPA6), RN38.2 (1)
GPA7-6: IC6.28 (GPA7), RN38.1
GPB0-6: IC6.1 (GPB0), RN39.4 (1)
GPB1-6: IC6.2 (GPB1), RN39.3 (1)
GPB2-6: IC6.3 (GPB2), RN39.2 (1)
GPB3-6: IC6.4 (GPB3), RN39.1
GPB4-6: IC6.5 (GPB4), RN40.4 (1)
GPB5-6: IC6.6 (GPB5), RN40.3 (1)
GPB6-6: IC6.7 (GPB6), RN40.2 (1)
GPB7-6: IC6.8 (GPB7), RN40.1
unnamed: IC6.17 (A2), J8.6, RN54.8 (2)
unnamed: IC6.15 (A0), J8.2, RN54.6 (2)
unnamed: IC6.16 (A1), J8.4, RN54.7 (2)
SCL: IC6.12 (SCL); also elsewhere on the board
SDA: IC6.13 (SDA); also elsewhere on the board
VCC: C6.1, IC6.9 (VDD), J8.1, J8.3, J8.5, RN45.5 (2), RN45.6 (2), RN45.7 (2), RN45.8 (2), RN46.5 (2), RN46.6 (2), RN46.7 (2), RN46.8 (2), RN47.5 (2), RN47.6 (2), RN47.7 (2), RN47.8 (2), RN48.5 (2), RN48.6 (2), RN48.7 (2), RN48.8 (2); also elsewhere on the board

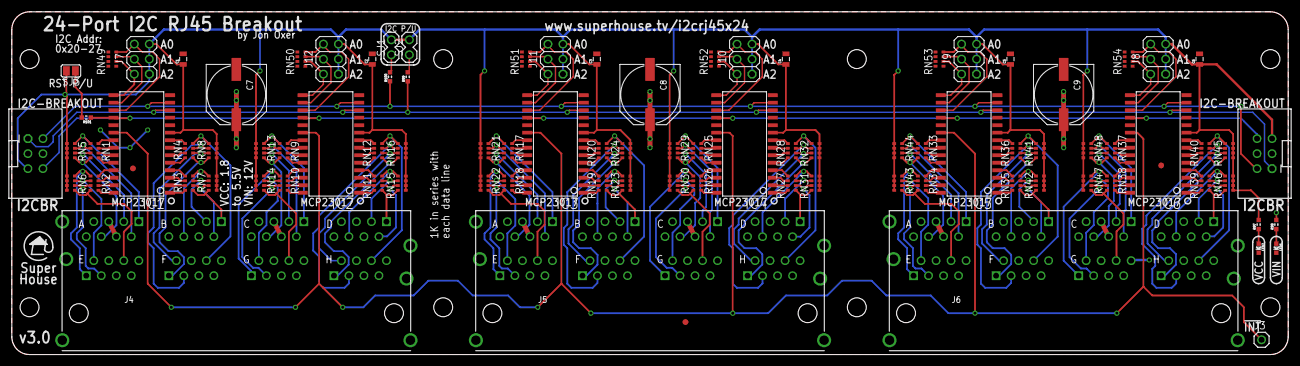
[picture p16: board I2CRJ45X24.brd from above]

Board: 2 copper layers, 216.0 x 58.0 mm, 94 parts (0 on the bottom side), 222 nets.

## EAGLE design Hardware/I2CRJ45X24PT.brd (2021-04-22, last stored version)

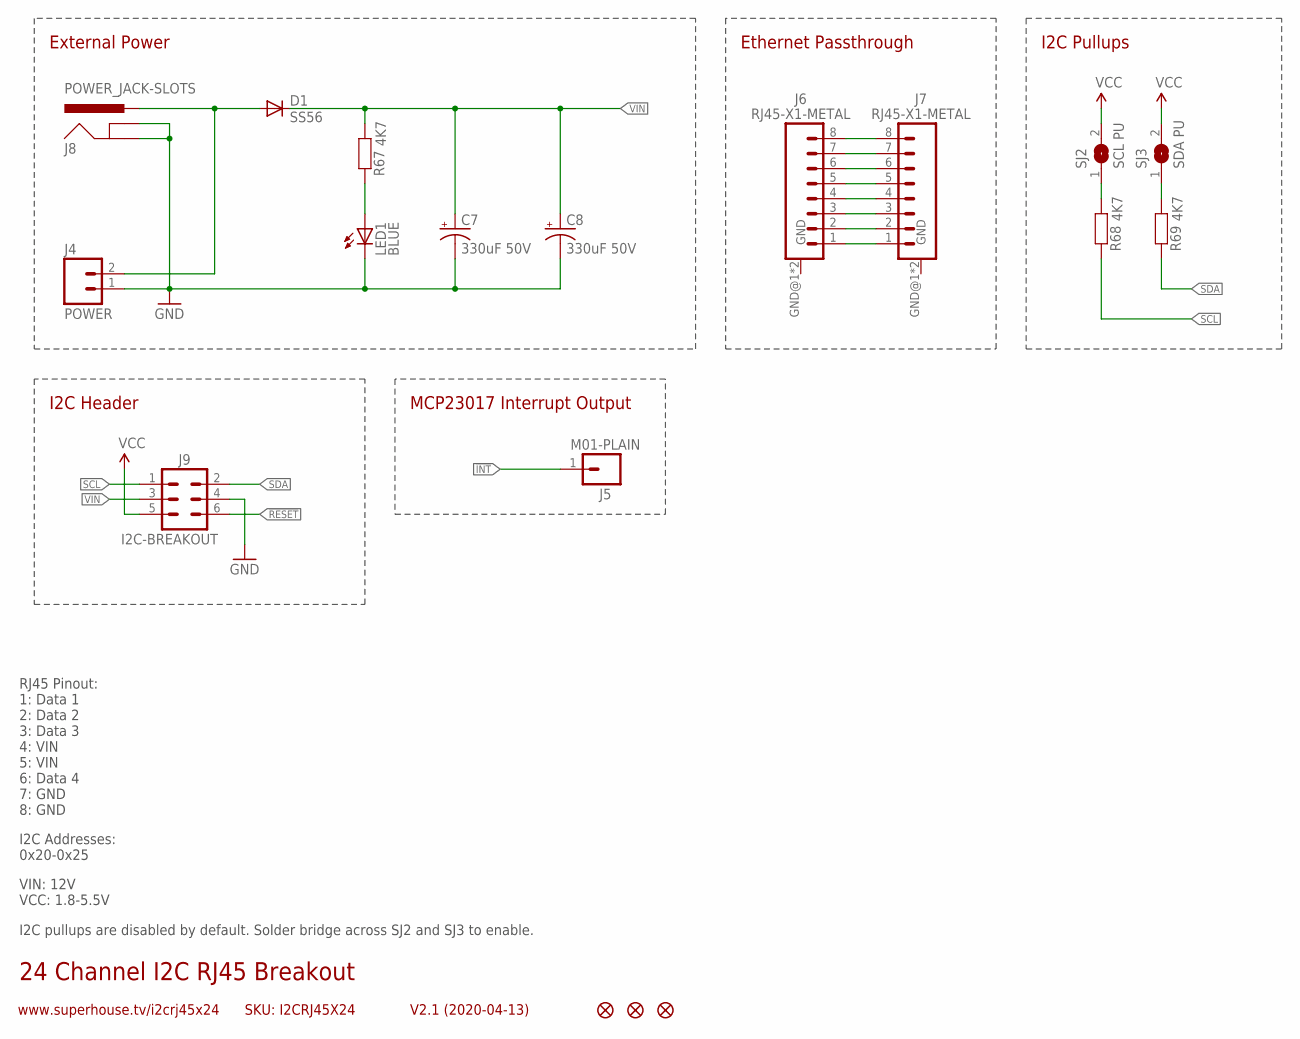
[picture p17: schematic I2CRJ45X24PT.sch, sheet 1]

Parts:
C7, C8: 330uF 50V; PANASONIC_G
D1: SS56; SMA-DIODE
FID1, FID2, FID3: FIDUCIAL1X2.5; FIDUCIAL-1X2.5
J4: POWER; SCREWTERMINAL-3.5MM-2
J5: M01-PLAIN; 1X01
J6, J7: RJ45-X1-METAL; RJ45-1X1
J8: POWER_JACK-SLOTS; POWER_JACK_SLOTS
J9: I2C-BREAKOUT; 2X03-SHROUDED
LED1: BLUE; LED3MM
R67, R68, R69: 4K7; R0603
SJ2: SCL PU; SJ
SJ3: SDA PU; SJ

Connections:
!INT: J5.1; also elsewhere on the board
!RESET: J9.6; also elsewhere on the board
GND: C7.-, C8.-, J4.1, J8.GND, J8.GNDBREAK, J9.4, LED1.K (C); also elsewhere on the board
unnamed: R68.2, SJ2.1
unnamed: R69.2, SJ3.1
unnamed: J6.1, J7.1
unnamed: J6.2, J7.2
unnamed: J6.3, J7.3
unnamed: J6.4, J7.4
unnamed: J6.5, J7.5
unnamed: J6.6, J7.6
unnamed: J6.7, J7.7
unnamed: J6.8, J7.8
unnamed: LED1.A, R67.1
unnamed: D1.A, J4.2, J8.PWR
SCL: J9.1, R68.1; also elsewhere on the board
SDA: J9.2, R69.1; also elsewhere on the board
VCC: J9.5, SJ2.2, SJ3.2; also elsewhere on the board
VIN: C7.+, C8.+, D1.C, J9.3, R67.2; also elsewhere on the board

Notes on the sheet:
24 Channel I2C RJ45 Breakout
V2.1 (2020-04-13)
www.superhouse.tv/i2crj45x24
SKU: I2CRJ45X24
RJ45 Pinout: 1: Data 1 2: Data 2 3: Data 3 4: VIN 5: VIN 6: Data 4 7: GND 8: GND
VIN: 12V VCC: 1.8-5.5V
I2C Addresses: 0x20-0x25
Ethernet Passthrough
External Power
I2C Header
MCP23017 Interrupt Output
I2C Pullups
I2C pullups are disabled by default. Solder bridge across SJ2 and SJ3 to enable.

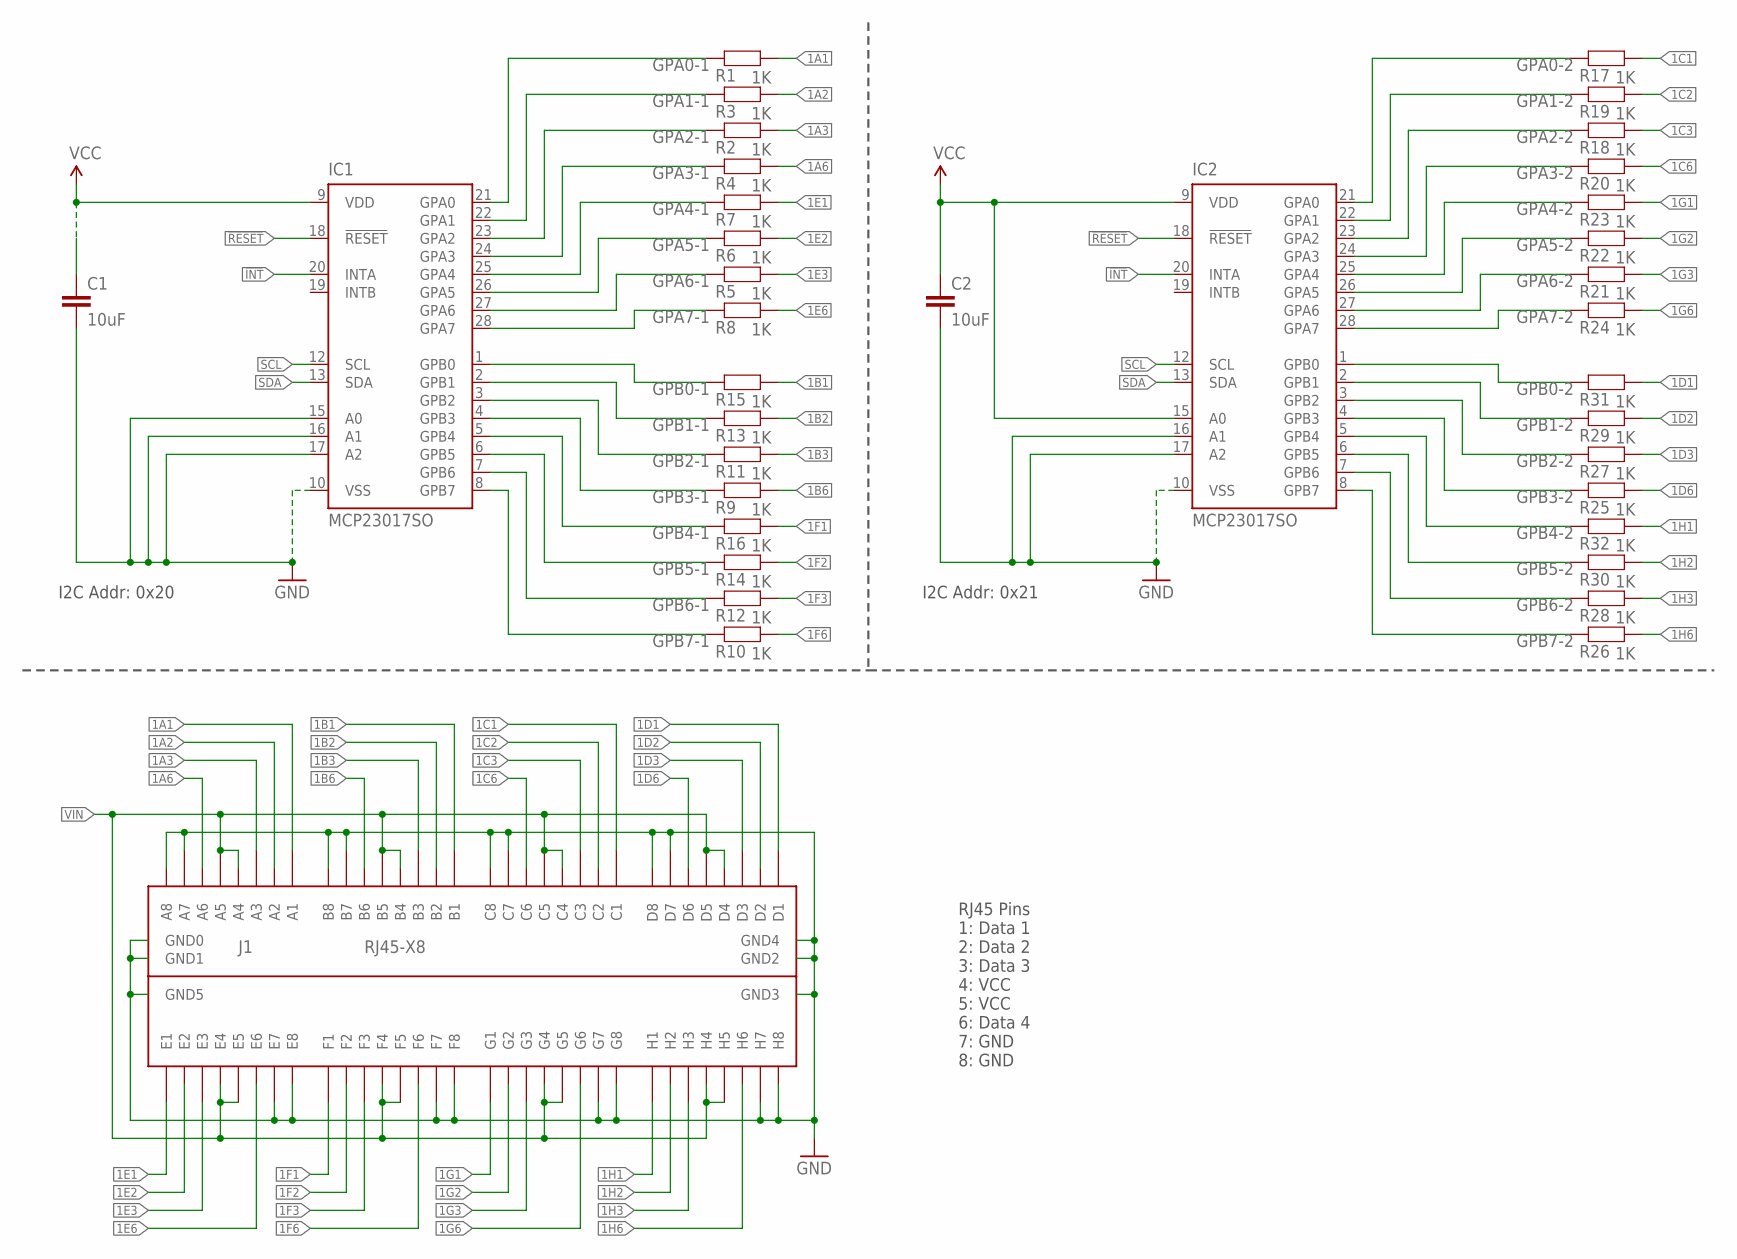
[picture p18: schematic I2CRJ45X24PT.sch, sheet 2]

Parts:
C1, C2: 10uF; C0805
IC1, IC2: MCP23017SO; SO28W
J1: RJ45-X8; RJ45-2X4
R1, R2, R3, R4, R5, R6, R7, R8, R9, R10, R11, R12, R13, R14, R15, R16, R17, R18, R19, R20, R21, R22, R23, R24, R25, R26, R27, R28, R29, R30, R31, R32: 1K; R0603

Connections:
1A1: J1.A1, R1.2
1A2: J1.A2, R3.2
1A3: J1.A3, R2.2
1A6: J1.A6, R4.2
1B1: J1.B1, R15.2
1B2: J1.B2, R13.2
1B3: J1.B3, R11.2
1B6: J1.B6, R9.2
1C1: J1.C1, R17.2
1C2: J1.C2, R19.2
1C3: J1.C3, R18.2
1C6: J1.C6, R20.2
1D1: J1.D1, R31.2
1D2: J1.D2, R29.2
1D3: J1.D3, R27.2
1D6: J1.D6, R25.2
1E1: J1.E1, R7.2
1E2: J1.E2, R6.2
1E3: J1.E3, R5.2
1E6: J1.E6, R8.2
1F1: J1.F1, R16.2
1F2: J1.F2, R14.2
1F3: J1.F3, R12.2
1F6: J1.F6, R10.2
1G1: J1.G1, R23.2
1G2: J1.G2, R22.2
1G3: J1.G3, R21.2
1G6: J1.G6, R24.2
1H1: J1.H1, R32.2
1H2: J1.H2, R30.2
1H3: J1.H3, R28.2
1H6: J1.H6, R26.2
!INT: IC1.20 (INTA), IC2.20 (INTA); also elsewhere on the board
!RESET: IC1.18 (!RESET), IC2.18 (!RESET); also elsewhere on the board
GND: C1.2, C2.2, IC1.10 (VSS), IC1.15 (A0), IC1.16 (A1), IC1.17 (A2), IC2.10 (VSS), IC2.16 (A1), IC2.17 (A2), J1.A7, J1.A8, J1.B7, J1.B8, J1.C7, J1.C8, J1.D7, J1.D8, J1.E7, J1.E8, J1.F7, J1.F8, J1.G7, J1.G8, J1.GND0, J1.GND1, J1.GND2, J1.GND3, J1.GND4, J1.GND5, J1.H7, J1.H8; also elsewhere on the board
GPA0-1: IC1.21 (GPA0), R1.1
GPA0-2: IC2.21 (GPA0), R17.1
GPA1-1: IC1.22 (GPA1), R3.1
GPA1-2: IC2.22 (GPA1), R19.1
GPA2-1: IC1.23 (GPA2), R2.1
GPA2-2: IC2.23 (GPA2), R18.1
GPA3-1: IC1.24 (GPA3), R4.1
GPA3-2: IC2.24 (GPA3), R20.1
GPA4-1: IC1.25 (GPA4), R7.1
GPA4-2: IC2.25 (GPA4), R23.1
GPA5-1: IC1.26 (GPA5), R6.1
GPA5-2: IC2.26 (GPA5), R22.1
GPA6-1: IC1.27 (GPA6), R5.1
GPA6-2: IC2.27 (GPA6), R21.1
GPA7-1: IC1.28 (GPA7), R8.1
GPA7-2: IC2.28 (GPA7), R24.1
GPB0-1: IC1.1 (GPB0), R15.1
GPB0-2: IC2.1 (GPB0), R31.1
GPB1-1: IC1.2 (GPB1), R13.1
GPB1-2: IC2.2 (GPB1), R29.1
GPB2-1: IC1.3 (GPB2), R11.1
GPB2-2: IC2.3 (GPB2), R27.1
GPB3-1: IC1.4 (GPB3), R9.1
GPB3-2: IC2.4 (GPB3), R25.1
GPB4-1: IC1.5 (GPB4), R16.1
GPB4-2: IC2.5 (GPB4), R32.1
GPB5-1: IC1.6 (GPB5), R14.1
GPB5-2: IC2.6 (GPB5), R30.1
GPB6-1: IC1.7 (GPB6), R12.1
GPB6-2: IC2.7 (GPB6), R28.1
GPB7-1: IC1.8 (GPB7), R10.1
GPB7-2: IC2.8 (GPB7), R26.1
SCL: IC1.12 (SCL), IC2.12 (SCL); also elsewhere on the board
SDA: IC1.13 (SDA), IC2.13 (SDA); also elsewhere on the board
VCC: C1.1, C2.1, IC1.9 (VDD), IC2.9 (VDD), IC2.15 (A0); also elsewhere on the board
VIN: J1.A4, J1.A5, J1.B4, J1.B5, J1.C4, J1.C5, J1.D4, J1.D5, J1.E4, J1.E5, J1.F4, J1.F5, J1.G4, J1.G5, J1.H4, J1.H5; also elsewhere on the board

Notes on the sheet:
RJ45 Pins 1: Data 1 2: Data 2 3: Data 3 4: VCC 5: VCC 6: Data 4 7: GND 8: GND
I2C Addr: 0x20
I2C Addr: 0x21

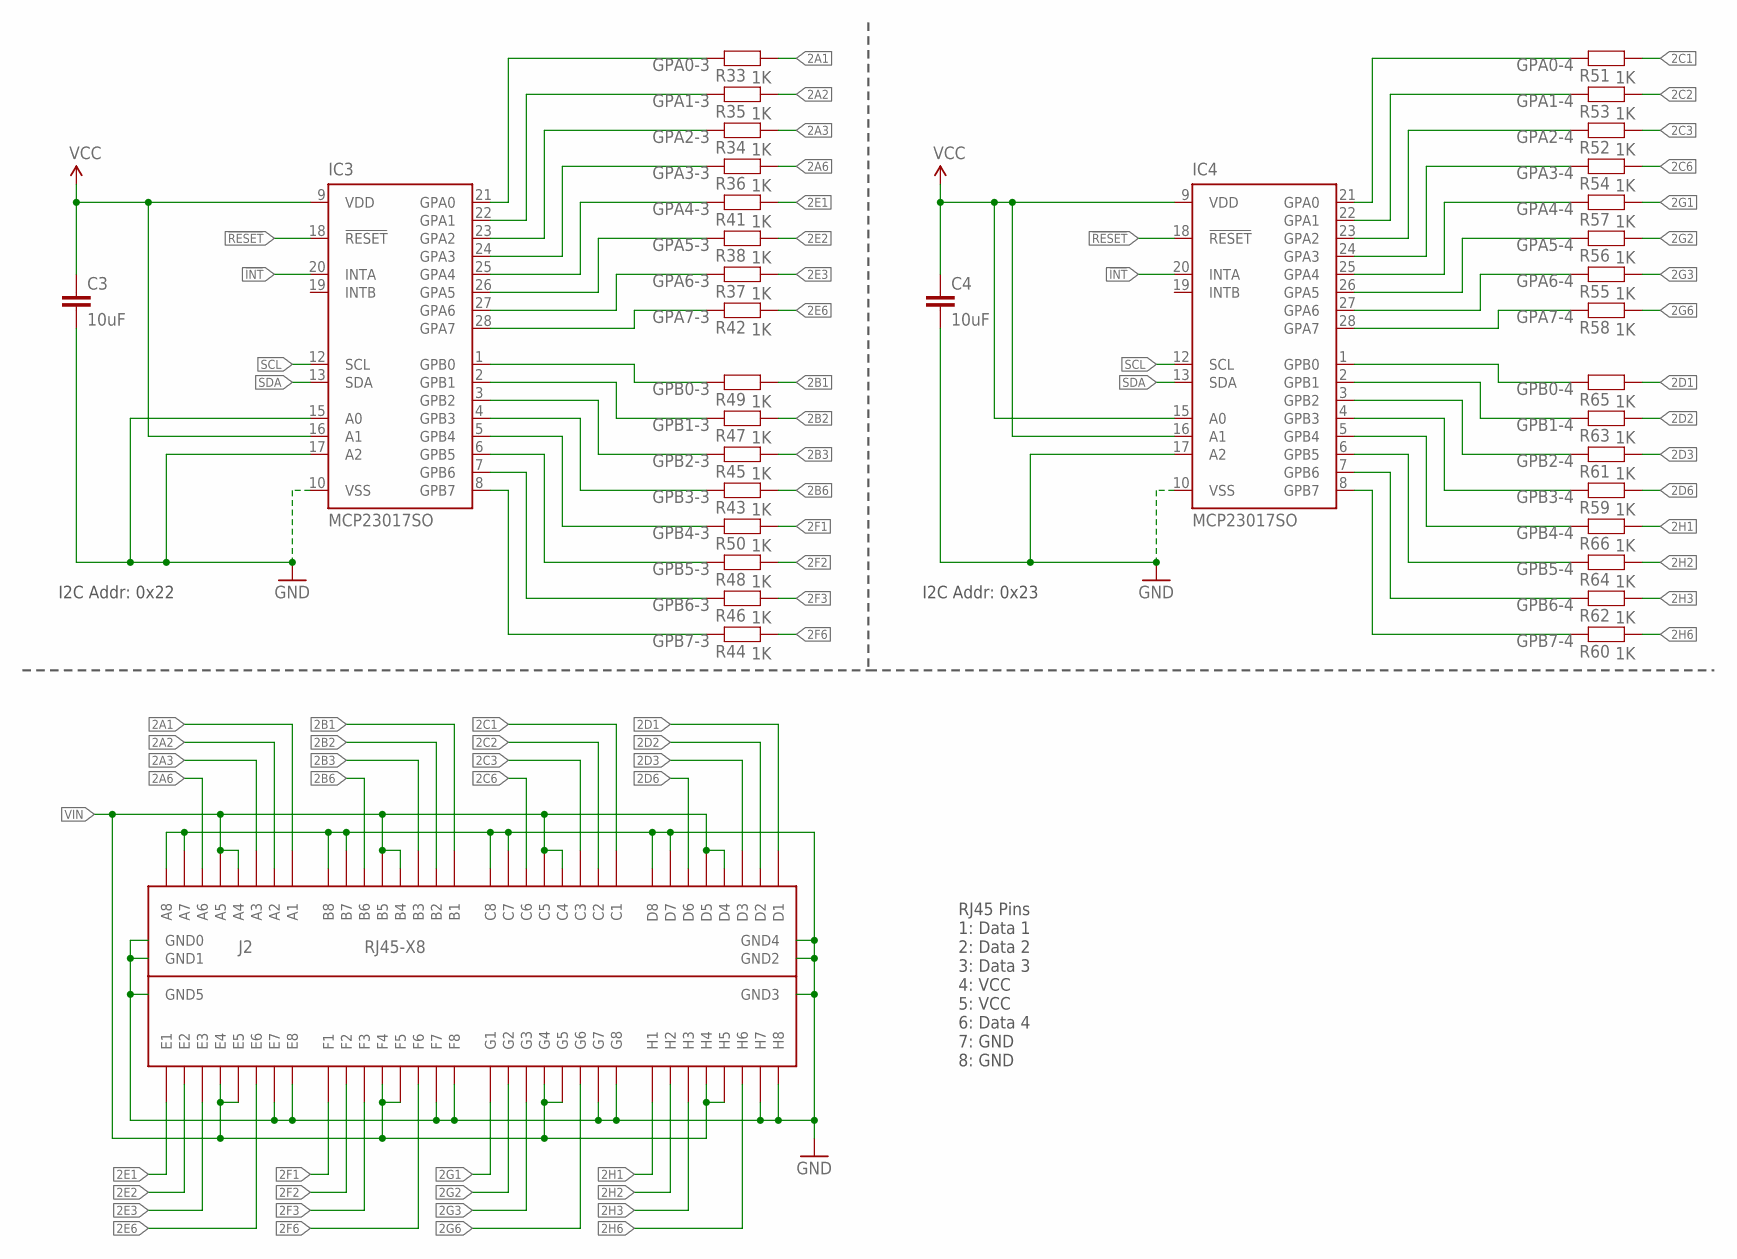
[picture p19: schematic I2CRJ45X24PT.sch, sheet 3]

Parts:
C3, C4: 10uF; C0805
IC3, IC4: MCP23017SO; SO28W
J2: RJ45-X8; RJ45-2X4
R33, R34, R35, R36, R37, R38, R41, R42, R43, R44, R45, R46, R47, R48, R49, R50, R51, R52, R53, R54, R55, R56, R57, R58, R59, R60, R61, R62, R63, R64, R65, R66: 1K; R0603

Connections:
2A1: J2.A1, R33.2
2A2: J2.A2, R35.2
2A3: J2.A3, R34.2
2A6: J2.A6, R36.2
2B1: J2.B1, R49.2
2B2: J2.B2, R47.2
2B3: J2.B3, R45.2
2B6: J2.B6, R43.2
2C1: J2.C1, R51.2
2C2: J2.C2, R53.2
2C3: J2.C3, R52.2
2C6: J2.C6, R54.2
2D1: J2.D1, R65.2
2D2: J2.D2, R63.2
2D3: J2.D3, R61.2
2D6: J2.D6, R59.2
2E1: J2.E1, R41.2
2E2: J2.E2, R38.2
2E3: J2.E3, R37.2
2E6: J2.E6, R42.2
2F1: J2.F1, R50.2
2F2: J2.F2, R48.2
2F3: J2.F3, R46.2
2F6: J2.F6, R44.2
2G1: J2.G1, R57.2
2G2: J2.G2, R56.2
2G3: J2.G3, R55.2
2G6: J2.G6, R58.2
2H1: J2.H1, R66.2
2H2: J2.H2, R64.2
2H3: J2.H3, R62.2
2H6: J2.H6, R60.2
!INT: IC3.20 (INTA), IC4.20 (INTA); also elsewhere on the board
!RESET: IC3.18 (!RESET), IC4.18 (!RESET); also elsewhere on the board
GND: C3.2, C4.2, IC3.10 (VSS), IC3.15 (A0), IC3.17 (A2), IC4.10 (VSS), IC4.17 (A2), J2.A7, J2.A8, J2.B7, J2.B8, J2.C7, J2.C8, J2.D7, J2.D8, J2.E7, J2.E8, J2.F7, J2.F8, J2.G7, J2.G8, J2.GND0, J2.GND1, J2.GND2, J2.GND3, J2.GND4, J2.GND5, J2.H7, J2.H8; also elsewhere on the board
GPA0-3: IC3.21 (GPA0), R33.1
GPA0-4: IC4.21 (GPA0), R51.1
GPA1-3: IC3.22 (GPA1), R35.1
GPA1-4: IC4.22 (GPA1), R53.1
GPA2-3: IC3.23 (GPA2), R34.1
GPA2-4: IC4.23 (GPA2), R52.1
GPA3-3: IC3.24 (GPA3), R36.1
GPA3-4: IC4.24 (GPA3), R54.1
GPA4-3: IC3.25 (GPA4), R41.1
GPA4-4: IC4.25 (GPA4), R57.1
GPA5-3: IC3.26 (GPA5), R38.1
GPA5-4: IC4.26 (GPA5), R56.1
GPA6-3: IC3.27 (GPA6), R37.1
GPA6-4: IC4.27 (GPA6), R55.1
GPA7-3: IC3.28 (GPA7), R42.1
GPA7-4: IC4.28 (GPA7), R58.1
GPB0-3: IC3.1 (GPB0), R49.1
GPB0-4: IC4.1 (GPB0), R65.1
GPB1-3: IC3.2 (GPB1), R47.1
GPB1-4: IC4.2 (GPB1), R63.1
GPB2-3: IC3.3 (GPB2), R45.1
GPB2-4: IC4.3 (GPB2), R61.1
GPB3-3: IC3.4 (GPB3), R43.1
GPB3-4: IC4.4 (GPB3), R59.1
GPB4-3: IC3.5 (GPB4), R50.1
GPB4-4: IC4.5 (GPB4), R66.1
GPB5-3: IC3.6 (GPB5), R48.1
GPB5-4: IC4.6 (GPB5), R64.1
GPB6-3: IC3.7 (GPB6), R46.1
GPB6-4: IC4.7 (GPB6), R62.1
GPB7-3: IC3.8 (GPB7), R44.1
GPB7-4: IC4.8 (GPB7), R60.1
SCL: IC3.12 (SCL), IC4.12 (SCL); also elsewhere on the board
SDA: IC3.13 (SDA), IC4.13 (SDA); also elsewhere on the board
VCC: C3.1, C4.1, IC3.9 (VDD), IC3.16 (A1), IC4.9 (VDD), IC4.15 (A0), IC4.16 (A1); also elsewhere on the board
VIN: J2.A4, J2.A5, J2.B4, J2.B5, J2.C4, J2.C5, J2.D4, J2.D5, J2.E4, J2.E5, J2.F4, J2.F5, J2.G4, J2.G5, J2.H4, J2.H5; also elsewhere on the board

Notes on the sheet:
RJ45 Pins 1: Data 1 2: Data 2 3: Data 3 4: VCC 5: VCC 6: Data 4 7: GND 8: GND
I2C Addr: 0x22
I2C Addr: 0x23


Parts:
C5, C6: 10uF; C0805
IC5, IC6: MCP23017SO; SO28W
J3: RJ45-X8; RJ45-2X4
R70, R71, R72, R73, R74, R75, R76, R77, R78, R79, R80, R81, R82, R83, R84, R85, R86, R87, R88, R89, R90, R91, R92, R93, R94, R95, R96, R97, R98, R99, R100, R101: 1K; R0603

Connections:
3A1: J3.A1, R70.2
3A2: J3.A2, R72.2
3A3: J3.A3, R71.2
3A6: J3.A6, R73.2
3B1: J3.B1, R84.2
3B2: J3.B2, R82.2
3B3: J3.B3, R80.2
3B6: J3.B6, R78.2
3C1: J3.C1, R86.2
3C2: J3.C2, R88.2
3C3: J3.C3, R87.2
3C6: J3.C6, R89.2
3D1: J3.D1, R100.2
3D2: J3.D2, R98.2
3D3: J3.D3, R96.2
3D6: J3.D6, R94.2
3E1: J3.E1, R76.2
3E2: J3.E2, R75.2
3E3: J3.E3, R74.2
3E6: J3.E6, R77.2
3F1: J3.F1, R85.2
3F2: J3.F2, R83.2
3F3: J3.F3, R81.2
3F6: J3.F6, R79.2
3G1: J3.G1, R92.2
3G2: J3.G2, R91.2
3G3: J3.G3, R90.2
3G6: J3.G6, R93.2
3H1: J3.H1, R101.2
3H2: J3.H2, R99.2
3H3: J3.H3, R97.2
3H6: J3.H6, R95.2
!INT: IC5.20 (INTA), IC6.20 (INTA); also elsewhere on the board
!RESET: IC5.18 (!RESET), IC6.18 (!RESET); also elsewhere on the board
GND: C5.2, C6.2, IC5.10 (VSS), IC5.15 (A0), IC5.16 (A1), IC6.10 (VSS), IC6.16 (A1), J3.A7, J3.A8, J3.B7, J3.B8, J3.C7, J3.C8, J3.D7, J3.D8, J3.E7, J3.E8, J3.F7, J3.F8, J3.G7, J3.G8, J3.GND0, J3.GND1, J3.GND2, J3.GND3, J3.GND4, J3.GND5, J3.H7, J3.H8; also elsewhere on the board
GPA0-5: IC5.21 (GPA0), R70.1
GPA0-6: IC6.21 (GPA0), R86.1
GPA1-5: IC5.22 (GPA1), R72.1
GPA1-6: IC6.22 (GPA1), R88.1
GPA2-5: IC5.23 (GPA2), R71.1
GPA2-6: IC6.23 (GPA2), R87.1
GPA3-5: IC5.24 (GPA3), R73.1
GPA3-6: IC6.24 (GPA3), R89.1
GPA4-5: IC5.25 (GPA4), R76.1
GPA4-6: IC6.25 (GPA4), R92.1
GPA5-5: IC5.26 (GPA5), R75.1
GPA5-6: IC6.26 (GPA5), R91.1
GPA6-5: IC5.27 (GPA6), R74.1
GPA6-6: IC6.27 (GPA6), R90.1
GPA7-5: IC5.28 (GPA7), R77.1
GPA7-6: IC6.28 (GPA7), R93.1
GPB0-5: IC5.1 (GPB0), R84.1
GPB0-6: IC6.1 (GPB0), R100.1
GPB1-5: IC5.2 (GPB1), R82.1
GPB1-6: IC6.2 (GPB1), R98.1
GPB2-5: IC5.3 (GPB2), R80.1
GPB2-6: IC6.3 (GPB2), R96.1
GPB3-5: IC5.4 (GPB3), R78.1
GPB3-6: IC6.4 (GPB3), R94.1
GPB4-5: IC5.5 (GPB4), R85.1
GPB4-6: IC6.5 (GPB4), R101.1
GPB5-5: IC5.6 (GPB5), R83.1
GPB5-6: IC6.6 (GPB5), R99.1
GPB6-5: IC5.7 (GPB6), R81.1
GPB6-6: IC6.7 (GPB6), R97.1
GPB7-5: IC5.8 (GPB7), R79.1
GPB7-6: IC6.8 (GPB7), R95.1
SCL: IC5.12 (SCL), IC6.12 (SCL); also elsewhere on the board
SDA: IC5.13 (SDA), IC6.13 (SDA); also elsewhere on the board
VCC: C5.1, C6.1, IC5.9 (VDD), IC5.17 (A2), IC6.9 (VDD), IC6.15 (A0), IC6.17 (A2); also elsewhere on the board
VIN: J3.A4, J3.A5, J3.B4, J3.B5, J3.C4, J3.C5, J3.D4, J3.D5, J3.E4, J3.E5, J3.F4, J3.F5, J3.G4, J3.G5, J3.H4, J3.H5; also elsewhere on the board

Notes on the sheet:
RJ45 Pins 1: Data 1 2: Data 2 3: Data 3 4: VCC 5: VCC 6: Data 4 7: GND 8: GND
I2C Addr: 0x24
I2C Addr: 0x25


Board: 2 copper layers, 275.0 x 50.0 mm, 129 parts (0 on the bottom side), 211 nets.

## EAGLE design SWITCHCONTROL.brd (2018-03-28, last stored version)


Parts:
ICSP: ICSP:MAIN; 2X03
J1, J5: Digital_0_7; 1X08
J2, J4: Analog; 1X08
J3: Digital_8_13; 1X10
J6: Digital_22_36; 1X08
J7: Digital_23_37; 1X08
J8: Digital_38_52; 1X08
J9: Digital_39_53; 1X08
J10: Power; 1X08
JP1, JP2: M02PTH; 1X02
S1: TAC_SWITCHPTH; TACTILE-PTH

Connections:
3V3: J10.4
5V: J10.5, JP2.1, JP2.2
A0: J2.1; also elsewhere on the board
A1: J2.2; also elsewhere on the board
A2: J2.3; also elsewhere on the board
A3: J2.4; also elsewhere on the board
A4: J2.5; also elsewhere on the board
A5: J2.6; also elsewhere on the board
A6: J2.7; also elsewhere on the board
A7: J2.8; also elsewhere on the board
A8: J4.1; also elsewhere on the board
A9: J4.2; also elsewhere on the board
A10: J4.3; also elsewhere on the board
A11: J4.4; also elsewhere on the board
A12: J4.5; also elsewhere on the board
A13: J4.6; also elsewhere on the board
A14: J4.7; also elsewhere on the board
A15: J4.8; also elsewhere on the board
AREF: J3.8
D0_RX: J1.1
D1_TX: J1.2
D2: J1.3
D3: J1.4
D4: J1.5
D5: J1.6
D6: J1.7
D7: J1.8
D8: J3.1
D9: J3.2
D10: J3.3
D11_MOSI: J3.4
D12_MISO: J3.5
D13_SCK: J3.6
D14: J5.8
D15: J5.7
D16: J5.6; also elsewhere on the board
D17: J5.5; also elsewhere on the board
D18: J5.4; also elsewhere on the board
D19: J5.3; also elsewhere on the board
D20: J5.2; also elsewhere on the board
D21: J5.1; also elsewhere on the board
D22: J6.8; also elsewhere on the board
D23: J7.8; also elsewhere on the board
D24: J6.7; also elsewhere on the board
D25: J7.7; also elsewhere on the board
D26: J6.6; also elsewhere on the board
D27: J7.6; also elsewhere on the board
D28: J6.5; also elsewhere on the board
D29: J7.5; also elsewhere on the board
D30: J6.4; also elsewhere on the board
D31: J7.4; also elsewhere on the board
D32: J6.3; also elsewhere on the board
D33: J7.3; also elsewhere on the board
D34: J6.2; also elsewhere on the board
D35: J7.2; also elsewhere on the board
D36: J6.1; also elsewhere on the board
D37: J7.1; also elsewhere on the board
D38: J8.8; also elsewhere on the board
D39: J9.8; also elsewhere on the board
D40: J8.7; also elsewhere on the board
D41: J9.7; also elsewhere on the board
D42: J8.6; also elsewhere on the board
D43: J9.6; also elsewhere on the board
D44: J8.5; also elsewhere on the board
D45: J9.5; also elsewhere on the board
D46: J8.4; also elsewhere on the board
D47: J9.4; also elsewhere on the board
D48: J8.3
D49: J9.3
D50_MISO: J8.2
D51_MOSI: J9.2
D52_SCK: J8.1
D53: J9.1
GND: J3.7, J10.6, J10.7, JP1.1, JP1.2, S1.1, S1.2; also elsewhere on the board
IOREF: J10.2
RESET: J10.3, S1.3, S1.4
SCL: J3.10
SDA: J3.9
VIN: J10.8; also elsewhere on the board

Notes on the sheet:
Freetronics ProtoShield Mega
V2.0 (2013-08-27)
www.freetronics.com/psm
SKU: PSM
Arduino Headers
GND
MISO
RESET
SCK
MOSI
DOG footprint with isolation jumper OLED Tilt sensor HUMID


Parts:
J11: RJ45-8X44UCON19514; RJ45-8X4
R1, R2, R3, R4, R5, R6, R7, R8, R9, R10, R11, R12, R13, R14, R15, R16: 1K; 0603

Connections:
A0: R1.1; also elsewhere on the board
A1: R3.1; also elsewhere on the board
A2: R2.1; also elsewhere on the board
A3: R4.1; also elsewhere on the board
A4: R7.1; also elsewhere on the board
A5: R6.1; also elsewhere on the board
A6: R5.1; also elsewhere on the board
A7: R8.1; also elsewhere on the board
A8: R15.1; also elsewhere on the board
A9: R13.1; also elsewhere on the board
A10: R11.1; also elsewhere on the board
A11: R9.1; also elsewhere on the board
A12: R16.1; also elsewhere on the board
A13: R14.1; also elsewhere on the board
A14: R12.1; also elsewhere on the board
A15: R10.1; also elsewhere on the board
GND: J11.A7, J11.A8, J11.B7, J11.B8, J11.C7, J11.C8, J11.D7, J11.D8, J11.GND0, J11.GND1, J11.GND2, J11.GND3, J11.GND4; also elsewhere on the board
PINA1: J11.A1, R16.2
PINA2: J11.A2, R14.2
PINA3: J11.A3, R12.2
PINA6: J11.A6, R10.2
PINB1: J11.B1, R15.2
PINB2: J11.B2, R13.2
PINB3: J11.B3, R11.2
PINB6: J11.B6, R9.2
PINC1: J11.C1, R7.2
PINC2: J11.C2, R6.2
PINC3: J11.C3, R5.2
PINC6: J11.C6, R8.2
PIND1: J11.D1, R1.2
PIND2: J11.D2, R3.2
PIND3: J11.D3, R2.2
PIND6: J11.D6, R4.2
VIN: J11.A4, J11.A5, J11.B4, J11.B5, J11.C4, J11.C5, J11.D4, J11.D5; also elsewhere on the board

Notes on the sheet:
To switch panels
RJ45 Pins 1: Data 1 2: Data 2 3: Data 3 4: VCC 5: VCC 6: Data 4 7: GND 8: GND


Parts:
J12: RJ45-8X44UCON19514; RJ45-8X4
R17, R18, R19, R20, R21, R22, R23, R24, R25, R26, R27, R28, R29, R30, R31, R32: 1K; 0603

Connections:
D16: R31.1; also elsewhere on the board
D17: R29.1; also elsewhere on the board
D18: R27.1; also elsewhere on the board
D19: R25.1; also elsewhere on the board
D20: R32.1; also elsewhere on the board
D21: R30.1; also elsewhere on the board
D22: R28.1; also elsewhere on the board
D23: R26.1; also elsewhere on the board
D40: R17.1; also elsewhere on the board
D41: R19.1; also elsewhere on the board
D42: R18.1; also elsewhere on the board
D43: R20.1; also elsewhere on the board
D44: R23.1; also elsewhere on the board
D45: R22.1; also elsewhere on the board
D46: R21.1; also elsewhere on the board
D47: R24.1; also elsewhere on the board
GND: J12.A7, J12.A8, J12.B7, J12.B8, J12.C7, J12.C8, J12.D7, J12.D8, J12.GND0, J12.GND1, J12.GND2, J12.GND3, J12.GND4; also elsewhere on the board
PINE1: J12.A1, R32.2
PINE2: J12.A2, R30.2
PINE3: J12.A3, R28.2
PINE6: J12.A6, R26.2
PINF1: J12.B1, R31.2
PINF2: J12.B2, R29.2
PINF3: J12.B3, R27.2
PINF6: J12.B6, R25.2
PING1: J12.C1, R23.2
PING2: J12.C2, R22.2
PING3: J12.C3, R21.2
PING6: J12.C6, R24.2
PINH1: J12.D1, R17.2
PINH2: J12.D2, R19.2
PINH3: J12.D3, R18.2
PINH6: J12.D6, R20.2
VIN: J12.A4, J12.A5, J12.B4, J12.B5, J12.C4, J12.C5, J12.D4, J12.D5; also elsewhere on the board

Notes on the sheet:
To switch panels
RJ45 Pins 1: Data 1 2: Data 2 3: Data 3 4: VCC 5: VCC 6: Data 4 7: GND 8: GND

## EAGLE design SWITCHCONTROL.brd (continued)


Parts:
J13: RJ45-8X44UCON19514; RJ45-8X4
R33, R34, R35, R36, R37, R38, R39, R40, R41, R42, R43, R44, R45, R46, R47, R48: 1K; 0603

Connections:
D24: R33.1; also elsewhere on the board
D25: R35.1; also elsewhere on the board
D26: R34.1; also elsewhere on the board
D27: R36.1; also elsewhere on the board
D28: R39.1; also elsewhere on the board
D29: R38.1; also elsewhere on the board
D30: R37.1; also elsewhere on the board
D31: R40.1; also elsewhere on the board
D32: R47.1; also elsewhere on the board
D33: R45.1; also elsewhere on the board
D34: R43.1; also elsewhere on the board
D35: R41.1; also elsewhere on the board
D36: R48.1; also elsewhere on the board
D37: R46.1; also elsewhere on the board
D38: R44.1; also elsewhere on the board
D39: R42.1; also elsewhere on the board
GND: J13.A7, J13.A8, J13.B7, J13.B8, J13.C7, J13.C8, J13.D7, J13.D8, J13.GND0, J13.GND1, J13.GND2, J13.GND3, J13.GND4; also elsewhere on the board
PINI1: J13.A1, R48.2
PINI2: J13.A2, R46.2
PINI3: J13.A3, R44.2
PINI6: J13.A6, R42.2
PINJ1: J13.B1, R47.2
PINJ2: J13.B2, R45.2
PINJ3: J13.B3, R43.2
PINJ6: J13.B6, R41.2
PINK1: J13.C1, R39.2
PINK2: J13.C2, R38.2
PINK3: J13.C3, R37.2
PINK6: J13.C6, R40.2
PINL1: J13.D1, R33.2
PINL2: J13.D2, R35.2
PINL3: J13.D3, R34.2
PINL6: J13.D6, R36.2
VIN: J13.A4, J13.A5, J13.B4, J13.B5, J13.C4, J13.C5, J13.D4, J13.D5; also elsewhere on the board

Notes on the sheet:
To switch panels
RJ45 Pins 1: Data 1 2: Data 2 3: Data 3 4: VCC 5: VCC 6: Data 4 7: GND 8: GND



Board: 2 copper layers, 162.3 x 104.1 mm, 65 parts (13 on the bottom side), 100 nets.

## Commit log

2018-03-28 Initial import of unfinished project
    [LightSwitchController.brd, LightSwitchController.sch]
2019-04-24 Renamed project files
    [SWITCHCONTROL.brd, SWITCHCONTROL.sch]
2019-07-30 Schematic and routing
    [I2CRJ45.brd, I2CRJ45.sch, SWITCHCONTROL.brd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]
2019-09-02 Fixed README
    [I2CRJ45.brd, I2CRJ45.sch, SWITCHCONTROLLER.brd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]
2019-09-04 Added DC power jack and screw terminal
    [SWITCHCONTROLLER.brd, SWITCHCONTROLLER.sch]
2019-09-04 Renamed project files to match SKU
    [LSC24.brd, LSC24.sch]
2019-09-07 Routing and silkscreen for Ethernet pass-through and external power
    [LSC24.brd, LSC24.sch]
2019-09-07 Board and schematic labelling
    [I2CRJ45X24.brd, I2CRJ45X24.sch]
2019-09-07 Added fiducials and optimised GND pathways
    [I2CRJ45X24.brd, I2CRJ45X24.sch]
2019-09-13 Final routing, plus ERC and DRC for v1.0 release
    [I2CRJ45X24.brd, I2CRJ45X24.sch]
2019-09-13 Minor silkscreen tweak
    [I2CRJ45X24.brd]
2020-04-08 Converted to I2C-BREAKOUT header for v2.0 release
    [I2CRJ45X24.brd, I2CRJ45X24.sch]
2020-04-30 Moved holes back from edge for v2.1 release
    [I2CRJ45X24.brd, I2CRJ45X24.sch]
2020-04-30 Added top layer SMT mount file
2021-03-11 Added PDF of schematic.
2021-04-12 Removed Ethernet passthrough and shortened board.
    [I2CRJ45X24.brd, I2CRJ45X24.sch]
2021-04-12 Removed outdated SMT mount file.
2021-04-12 Removed outdated schematic PDF.
2021-04-12 Moved hardware files into subdirectory.
    [I2CRJ45X24.brd, I2CRJ45X24.sch]
2021-04-12 Updated README to match shortened board.
2021-04-13 Renumbered parts to optimise production.
    [I2CRJ45X24.brd, I2CRJ45X24.sch]
2021-04-13 Added render of PCB.
2021-04-13 Embedded render of PCB.
2021-04-15 Major clean-up in preparation for recreating x8 and x16 versions based on the x24 version. Moved rear silkscreen into left third. Increased size of all data traces. Improved bottom power plane pour. 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
    [I2CRJ45X24.brd, I2CRJ45X24.sch]
2021-04-15 Added weak pull-up on RESET line.
    [I2CRJ45X24.brd, I2CRJ45X24.sch]
2021-04-15 Bumped version to v3.0 for release.
    [I2CRJ45X24.brd, I2CRJ45X24.sch]
2021-04-15 Major rework for v3.0 release of all versions.
    [I2CRJ45X24.brd, I2CRJ45X24.sch]
2021-04-22 Consolidated files from 24-port passthrough version into LSC project.
    [I2CRJ45X24PT.brd, I2CRJ45X24PT.sch]
2021-04-22 Consolidated files from 8-port version into LSC project.
    [I2CRJ45X8.brd, I2CRJ45X8.sch]
2021-04-22 Consolidated files from 16-port version into LSC project.
    [I2CRJ45X16.brd, I2CRJ45X16.sch]
2021-04-22 Began replacement of discrete resistors with resistor arrays.
    [I2CRJ45X24.brd, I2CRJ45X24.sch]
2021-04-24 initial changes to get working locally added support for watchdog changed button numbering to 0-based (i.e. 0-95) added support for custom MQTT base topic
2021-04-25 Progress on converting resistors to arrays and adding pullups.
    [I2CRJ45X24.brd, I2CRJ45X24.sch]
2021-04-25 Moved string into flash memory and applied automatic Arduino formatting.
2021-04-25 Use forked SH1106 library to drive I2C OLED display.
2021-04-25 Added image of assembled prototype.
2021-04-26 store button state for each chip in a single byte
2021-04-26 improve i2c scanner to detect presence of oled and gaps in mcp23017 addresses
2021-05-03 add support for different button event types
2021-05-06 scan for oled + button mcp display startup message
2021-05-06 add button event display
2021-05-20 add usm firmware for handling button/switch/contact inputs (#4)
2021-05-21 add better handling for ignored MCPs during I2C scan
2021-05-21 add support for TOGGLE switches (#5)
2021-05-27 OLED integration (#9)
    * more ram to save
    save ram by avoiding "static" where possible
    * Integration of OLED support
    integrated OLED support with port animation and event display at buttom line. OLED will be dimmed after some time of inactivity (parameter in config.h). Renamed everyting to USM and event.
    * some minor updates
    show MAC addess on OLED
    seperated OLED from I2C scan loop
    turn OFF OLED when DIM is set to 0 / otherwise dim
    made defines consistant
    * final changes
2021-05-30 remove ENABLE_OLED config variable - rely on I2C scanner minor code formatting
2021-05-30 add support for rotary encoder inputs (#10)
2021-06-04 Replace discrete resistors with resistor networks. Add hardware pull-ups to all input lines. Routing, ERC, and DRC for v3.0 release.
    [I2CRJ45X24.brd, I2CRJ45X24.sch]
2021-06-04 Added render of v3.0 24-port board.
2021-06-08 Major rework: rerouted entire board.
    [I2CRJ45X24.brd, I2CRJ45X24.sch]
2021-06-08 Regenerated 16-port version from updated 24-port version.
    [I2CRJ45X16.brd, I2CRJ45X16.sch]
2021-06-08 Regenerated 8-port version from updated 16-port version.
    [I2CRJ45X8.brd, I2CRJ45X8.sch]
2021-06-08 Increased track size on VCC.
    [I2CRJ45X24.brd]
2021-06-08 fix a couple of errors when compiling for ESP8266 and ESP32 (#11)
2021-06-18 speed up button client detection by 50ms
2021-07-04 remove usage of min() as not supported on ESP32 (#19)
2021-07-20 Removed I2C breakouts that are now in their own dedicated repository.
    [I2CRJ45X16.brd, I2CRJ45X16.sch, I2CRJ45X24.brd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]
2021-07-26 default all inputs to SWITCH (instead of BUTTON) on startup (#26)

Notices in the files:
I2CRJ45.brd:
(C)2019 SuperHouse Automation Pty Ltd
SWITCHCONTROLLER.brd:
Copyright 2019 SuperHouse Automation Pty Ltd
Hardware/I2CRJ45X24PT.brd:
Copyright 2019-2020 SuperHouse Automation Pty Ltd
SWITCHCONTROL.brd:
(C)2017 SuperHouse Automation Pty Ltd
